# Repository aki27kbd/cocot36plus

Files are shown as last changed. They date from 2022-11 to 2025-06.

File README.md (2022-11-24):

# cocot36plus

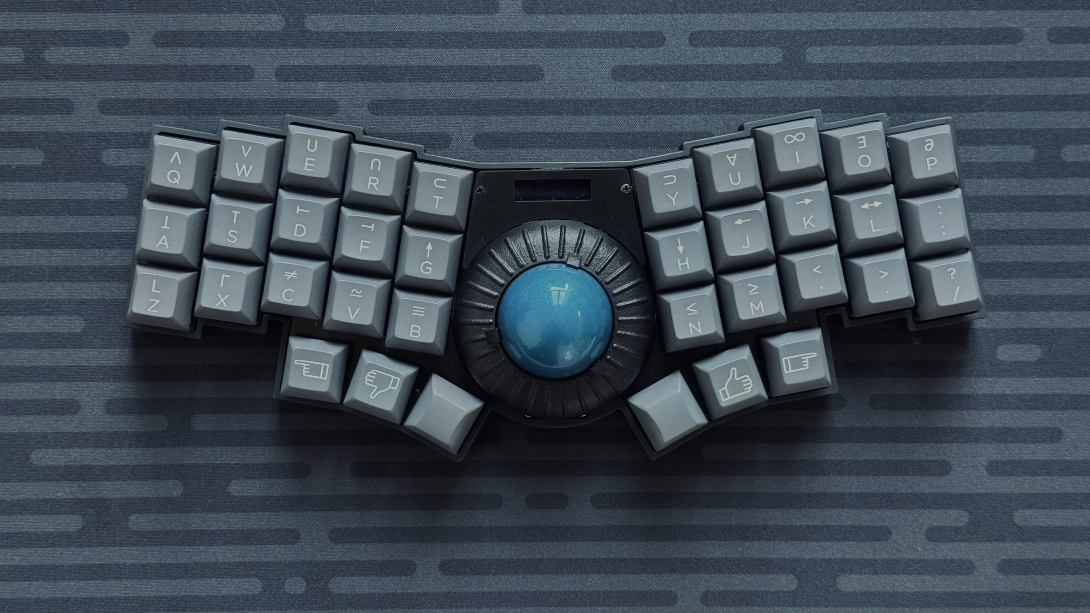
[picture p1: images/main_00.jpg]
cocot36plus_main00


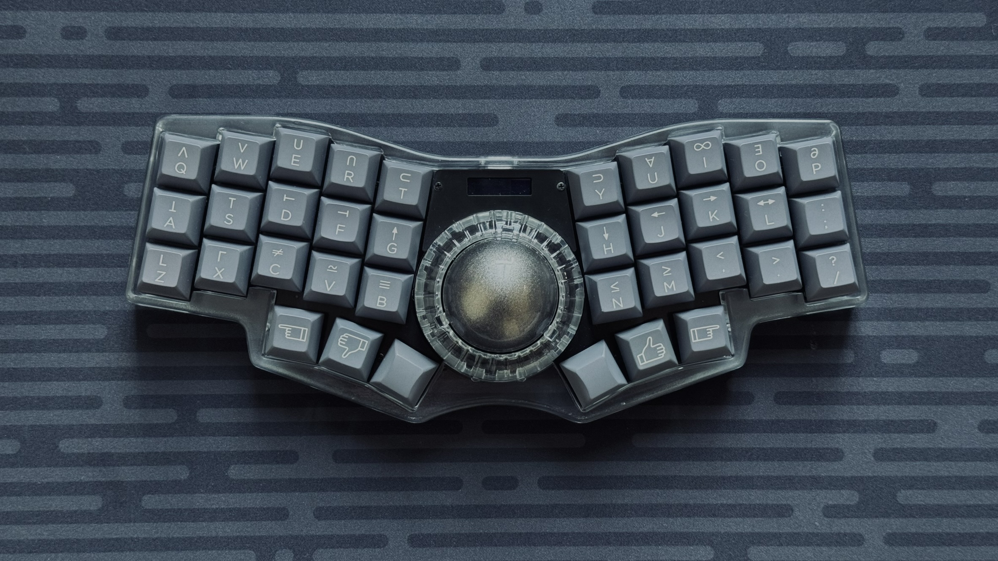
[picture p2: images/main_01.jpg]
cocot36plus_main01


cocot36plus is a column staggered keyboard with 36 keys, a 34mm-trackball and a scroll ring.

- Keyboard Maintainer: [aki27kbd](https://github.com/aki27kbd) [@aki27kbd](https://twitter.com/aki27kbd)
- Hardware Supported: cocot36plus PCB, RP2040 on board
- Hardware Availability: [BOOTH](https://aki27.booth.pm)

Build Guide [JP](doc/buildguide.md) / [EN](doc/buildguide_en.md)

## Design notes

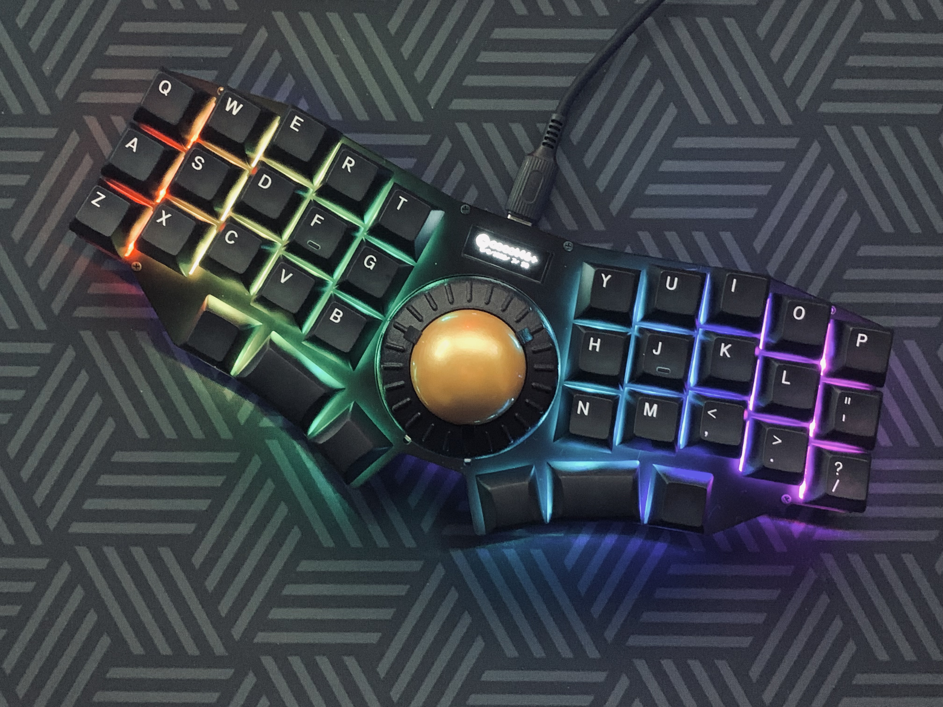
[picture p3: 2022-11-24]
v1/images/main_00.jpg

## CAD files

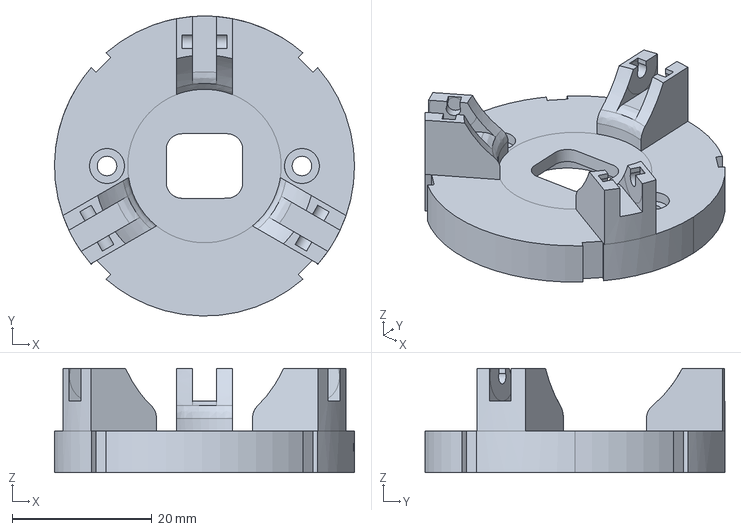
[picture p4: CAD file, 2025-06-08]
hardware/cocot36plus_v2_34mm_ballbase_rev.stp
43.0 x 43.0 x 15.0 mm

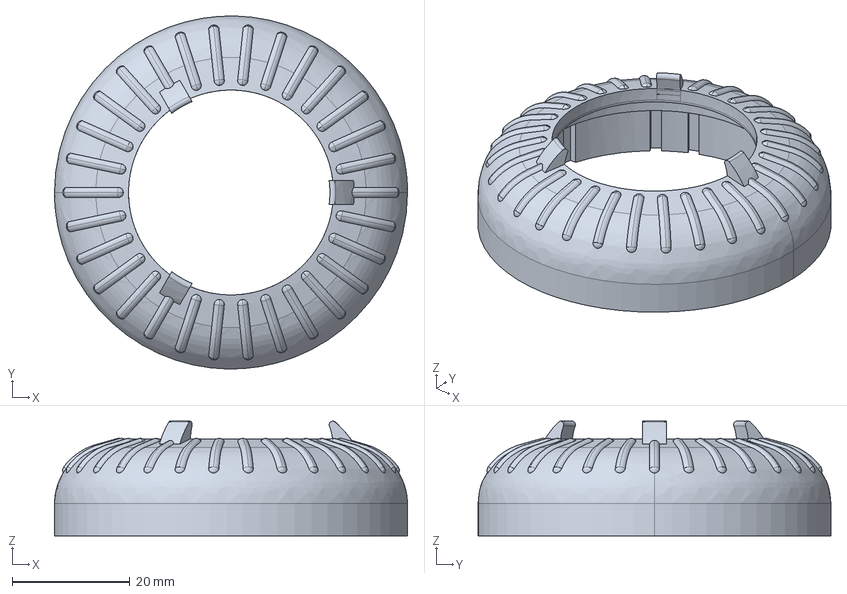
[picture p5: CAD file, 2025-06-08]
hardware/cocot36plus_v2_BallCover_34mm_MJF.stp
60.0 x 60.0 x 19.5 mm

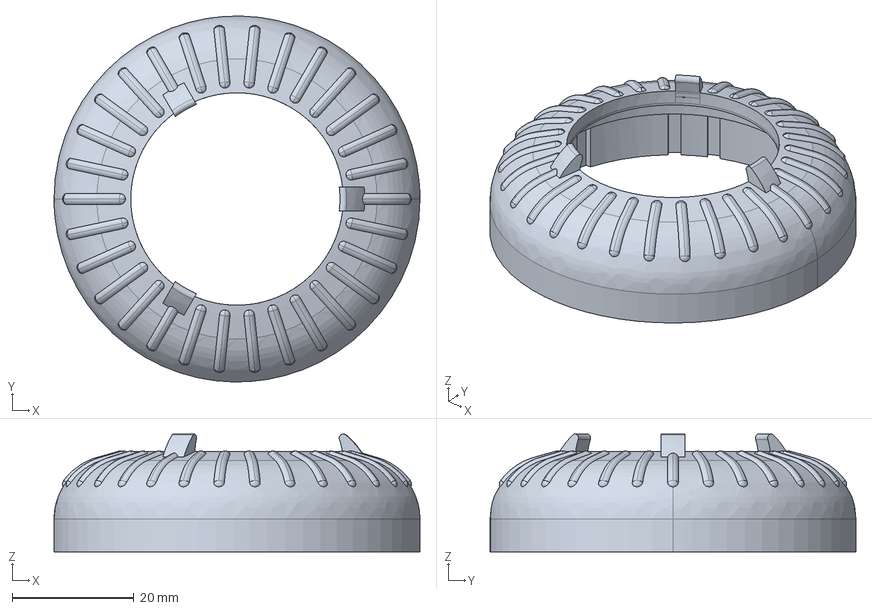
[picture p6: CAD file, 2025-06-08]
hardware/cocot36plus_v2_BallCover_34mm_ClearResin.stp
60.0 x 60.0 x 19.3 mm

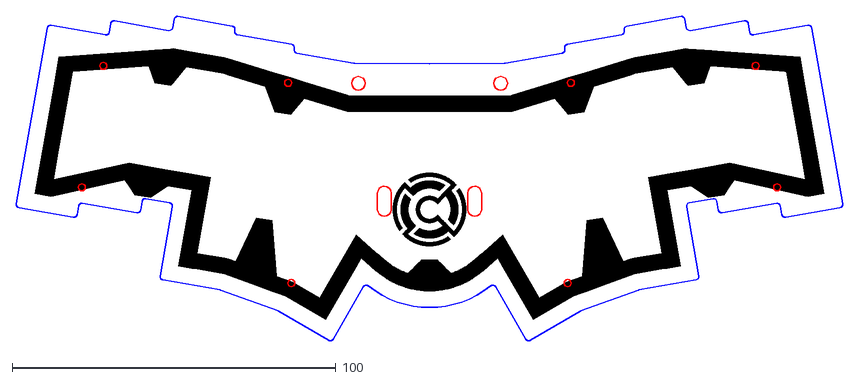
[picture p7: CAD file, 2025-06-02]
hardware/cocot36plus_v2_Acrylic_Bottom.dxf
255.4 x 100.3

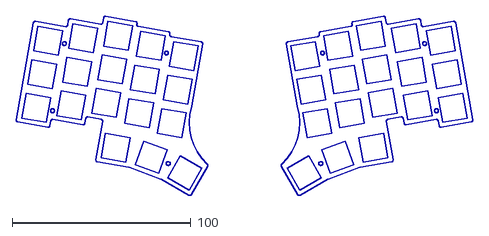
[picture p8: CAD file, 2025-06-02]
hardware/cocot36plus_v2_Switch_Plate.dxf
255.5 x 100.4

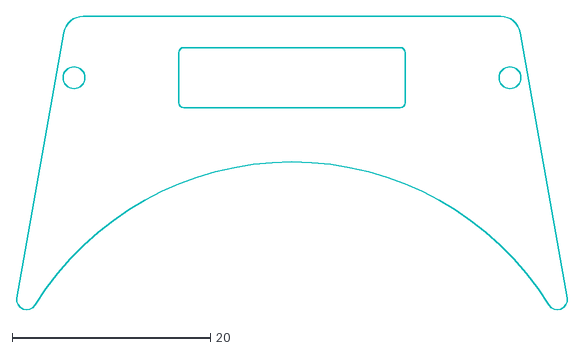
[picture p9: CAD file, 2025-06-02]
hardware/cocot36plus_v2_Cover_Plate.dxf
55.7 x 29.7

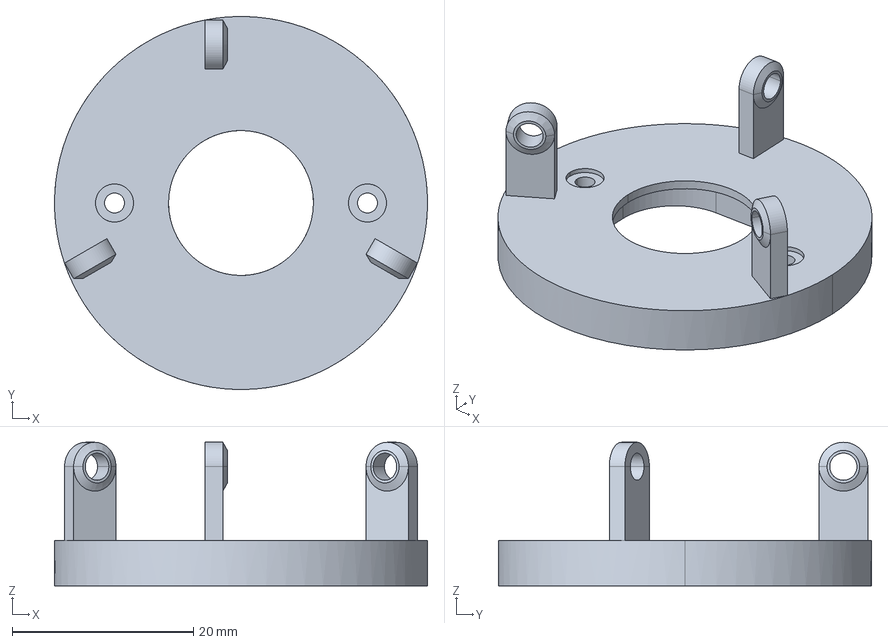
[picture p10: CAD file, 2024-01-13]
hardware/BallBase_34mm_Bearing.stp
41.2 x 41.2 x 15.9 mm

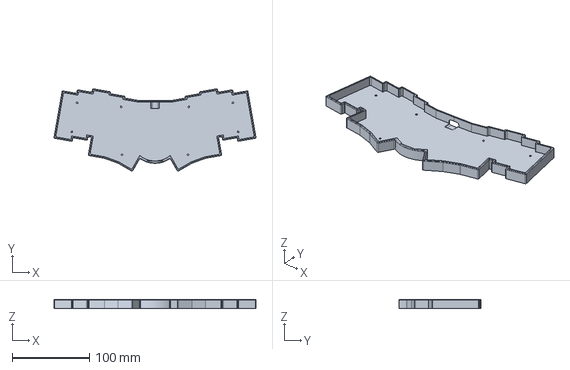
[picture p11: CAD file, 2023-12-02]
hardware/cocot36plus_v2_TrayMountCase_LowPro.stp
261.1 x 106.5 x 11.6 mm

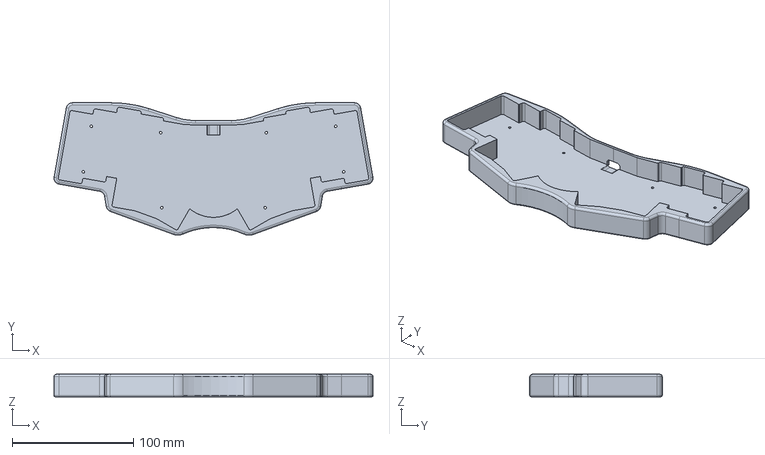
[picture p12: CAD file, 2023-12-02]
hardware/cocot36plus_v2_TrayMountCase.stp
263.3 x 109.4 x 18.6 mm

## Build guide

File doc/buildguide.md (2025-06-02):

# Build Guide

cocot36plus_main00

cocot36plus_main01

cocot36plus v2のビルドガイドになります。  
v1のビルドガイドは[こちら](https://github.com/aki27kbd/cocot36plus/blob/main/v1/doc/buildguide.md)を参照してください。

cocot36plusは中央に34mmトラックボールとスクロールリングを搭載したカラムスタッガード30%キーボードです。コンパクトながら豊富な機能を搭載しています。
- 中央にトラックボールとスクロールリングを配置
- フルキーバックライト & アンダーグロウLED & RGBマトリクス対応
- MCUはオンボードRP2040

また、ボールカバーを兼ねたスクロールリングは逆さにしてもボールが落ちず、かつ片手でボールの着脱が可能な設えとなっています。容易なボールのメンテナンスが可能となりました。

## 部品
### キット付属品

|名前|数|備考|
|---|---|---|
|PCB|1枚||
|スイッチプレート|2枚||
|アクリルボトムプレート|1枚||
|マウスセンサー（PMW3360）|1個||
|リングエンコーダ（PER601）|1個||
|OLED|1個||
|OLED用ピンヘッダ|1個||
|OLED用ピンソケット|1個||
|ベアリングローラー|3個||
|ステンレス棒×3|3本|
|シリコンチューブ|1本|
|M2ねじ 8mm|2本|
|M2ナット|2個|
|M2ねじ 4mm|20本|
|M2スペーサー 9mm|10本||
|ゴム脚|6個||
|3Dプリントボールベース|1個||
|3Dプリントボールカバー|1個||

### キット以外に必要なもの

|名前|数|備考|
|---|---|---|
|キースイッチ|36個|MX互換|
|キーキャップ|36個|MX互換|
|トラックボール（34mmボール）|1個||
|USB-TypeCケーブル|1本||

## 組み立て
### 部品確認

  まずはキット付属品に記載されたパーツが揃っているか確認ください。  
  その他上述の「キット以外に必要なもの」を揃えた上で組み立てに取り掛かってください。

  - タブ付きPCBの場合にはタブを割って切り離し、切断面を軽くヤスリがけしてください。
  - PCB、スイッチプレートの側面を油性マジックなどで黒く塗ると見栄えが良くなります。ぜひ試してみてください。

  上:未塗装 / 下:塗装済  
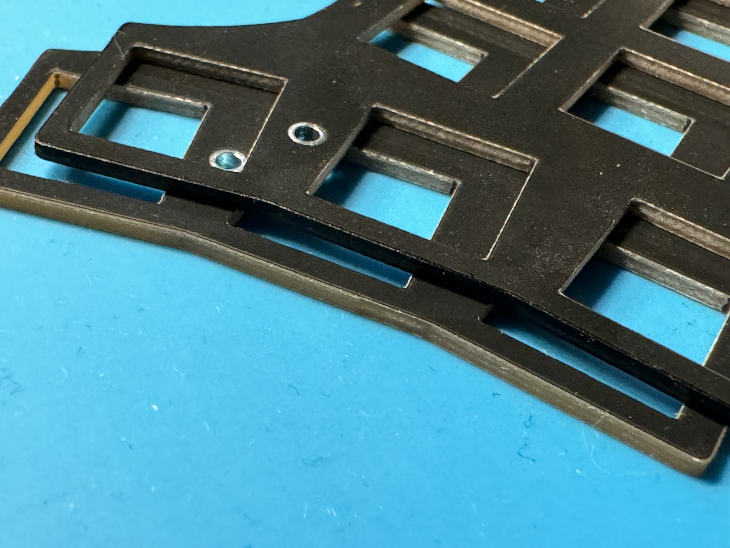
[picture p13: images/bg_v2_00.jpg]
cocot36plus_bg_00
  

### スイッチソケット

  スイッチソケットがはんだ付けされていない基板の場合、ソケットのはんだ付けを行ってください。  

### マウスセンサー

  マウスセンサー（PMW3360）を基板裏面から写真の向きに設置し、表面からはんだ付けを行います。シルクの●印と基板の●印の位置が合うように注意してください。  
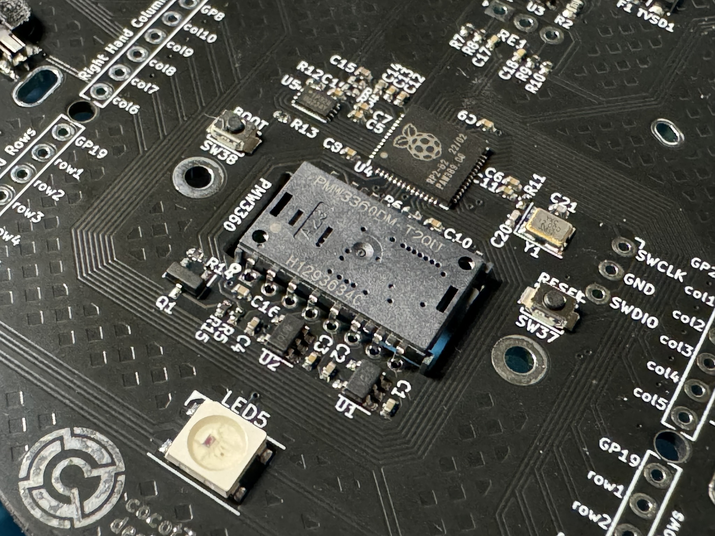
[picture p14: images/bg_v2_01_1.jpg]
cocot36plus_bg_01_1
  

  センサーの脚がしっかり奥まで入った状態で、浮かないようにマスキングテープなどで固定します。  
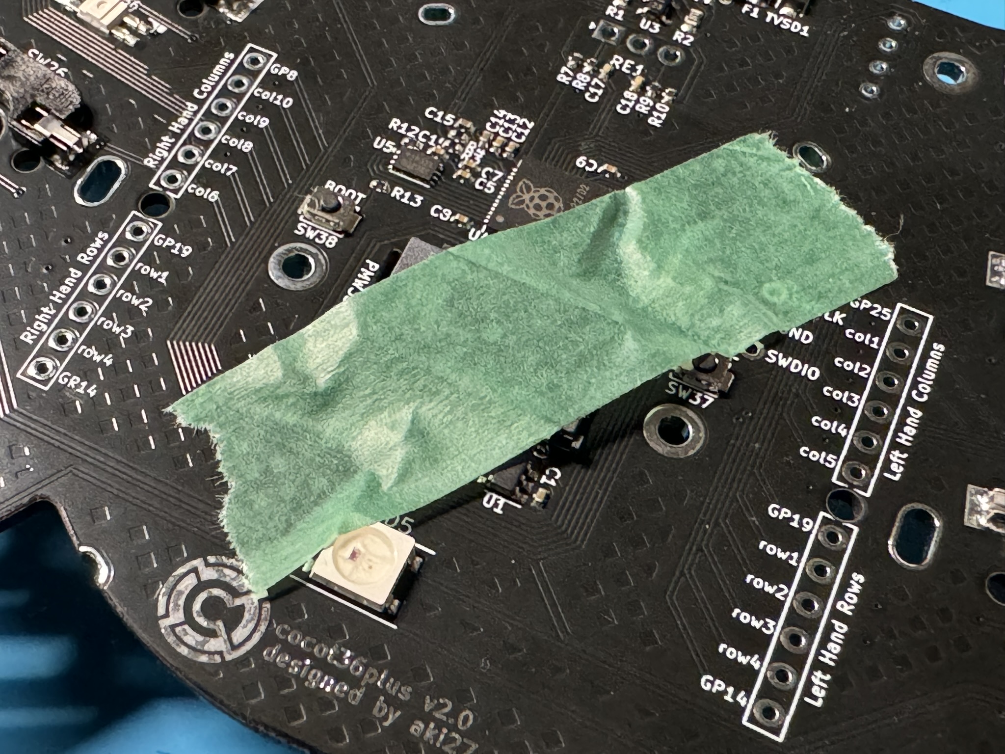
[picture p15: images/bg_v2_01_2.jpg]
cocot36plus_bg_01_2
  

  表面から16本の脚をはんだ付けします。センサーに貼られているテープを剥がし、表面からレンズを付けます。  
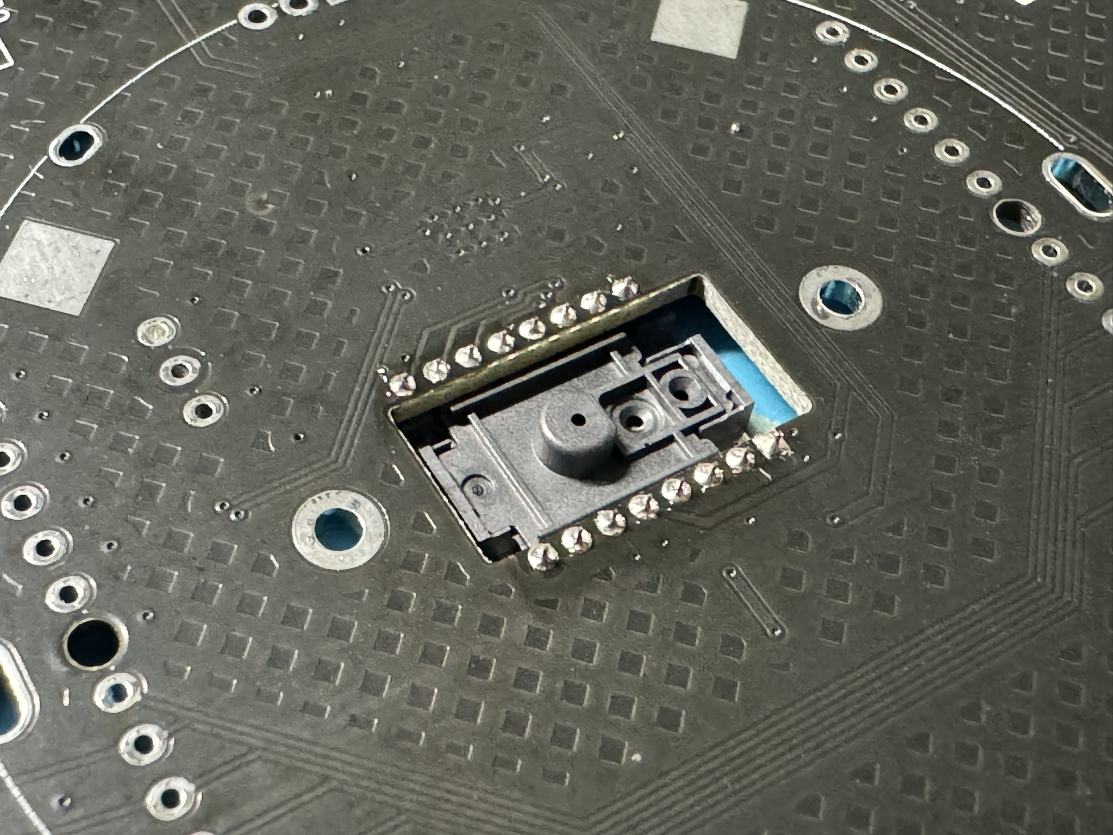
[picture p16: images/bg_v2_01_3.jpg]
cocot36plus_bg_01_3
  

### OLED

  OLED用ピンソケットをPCB表側から挿し、マスキングテープなどで固定します。
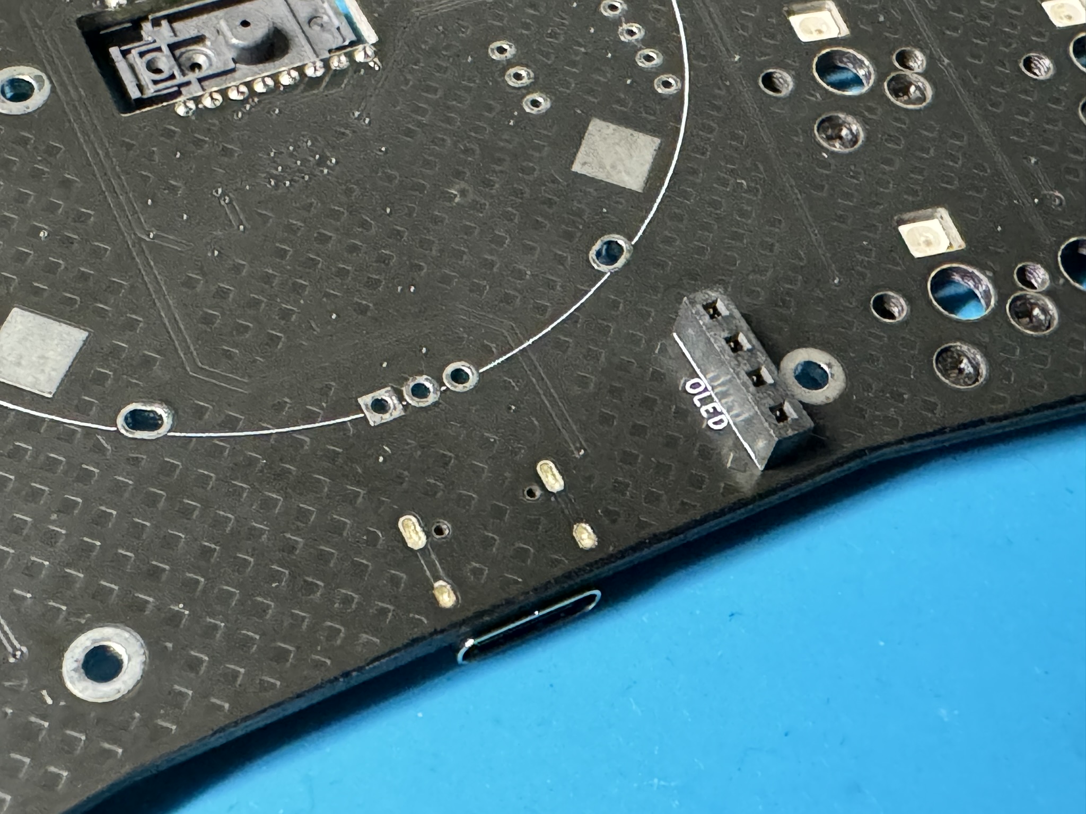
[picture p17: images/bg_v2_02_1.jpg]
cocot36plus_bg_02_1
  

  PCB裏面からピンソケットの脚4本をはんだ付けします。
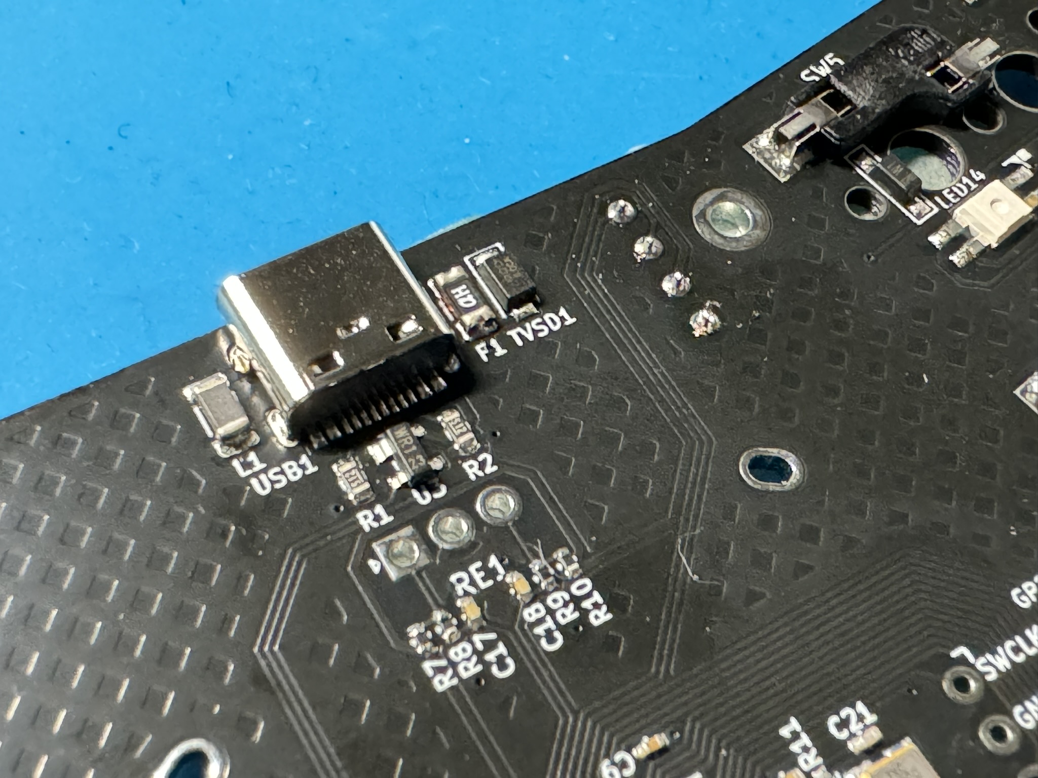
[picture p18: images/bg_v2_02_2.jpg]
cocot36plus_bg_02_2
  

  ピンヘッダを表側から挿し、その上からOLEDを挿します。OLEDの上面より飛び出しているピンヘッダをニッパーでカットし、はんだ付けします。OLEDモジュールが傾かないように固定した上ではんだ付けを行ってください。  
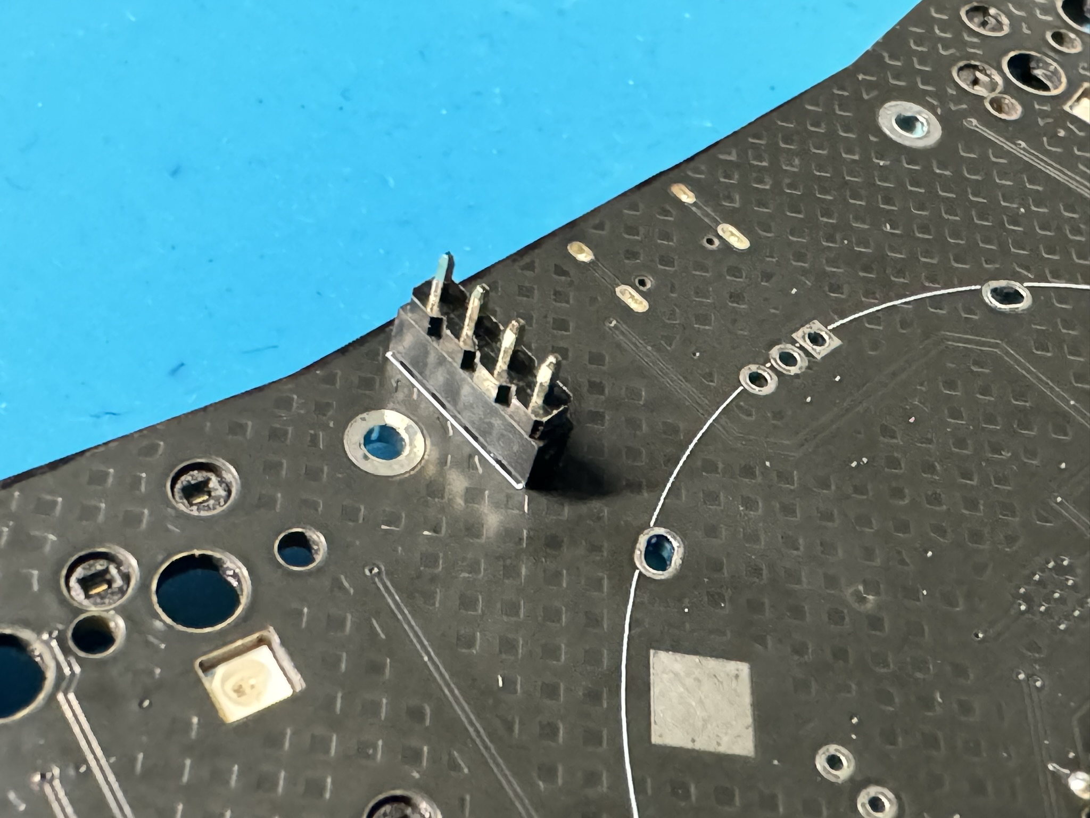
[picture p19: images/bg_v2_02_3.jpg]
cocot36plus_bg_02_3
  

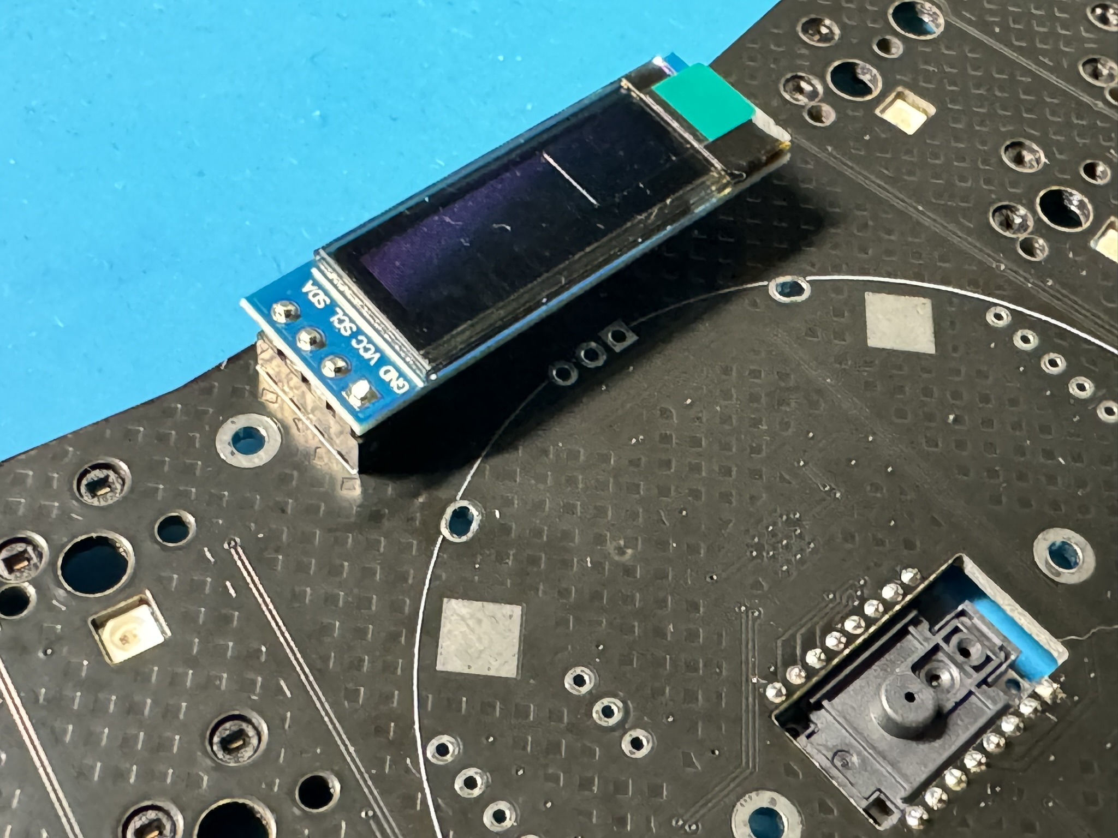
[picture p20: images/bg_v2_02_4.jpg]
cocot36plus_bg_02_4
  

### スクロールリング

  スクロールリングをPCB表面から差し込み、裏面の3か所はんだ付けを行います。  
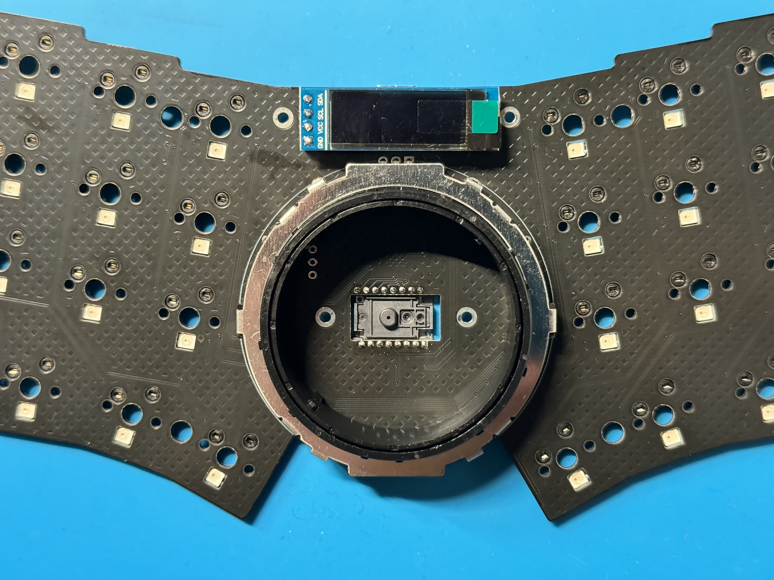
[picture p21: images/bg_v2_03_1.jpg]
cocot36plus_bg_03_1
  

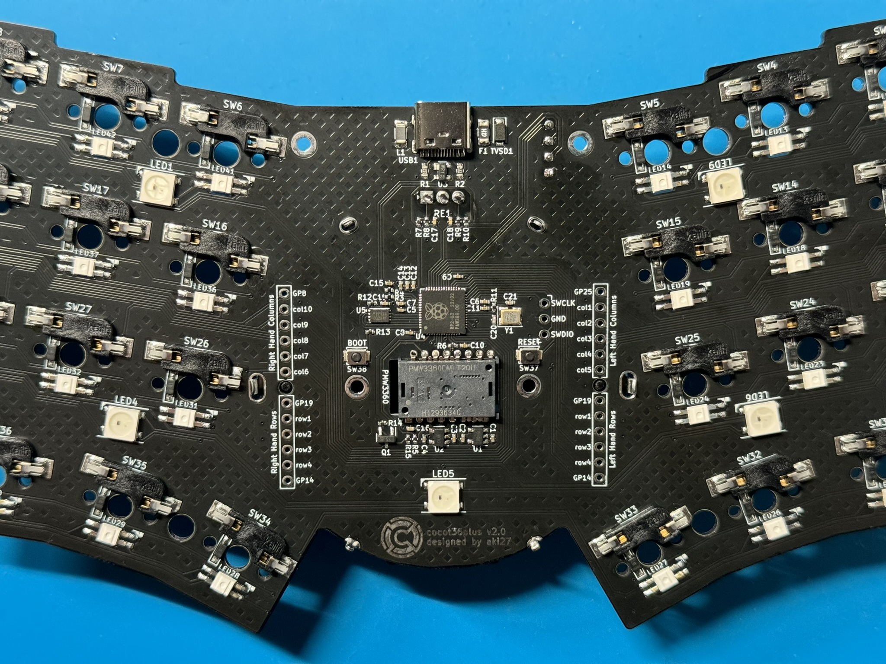
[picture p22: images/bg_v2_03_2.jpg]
cocot36plus_bg_03_2
  

### 組み立て

  ボールベースにベアリングローラーを固定します。写真の向きに合わせてベアリングローラー、M3ネジ、M3ナットで固定します。ベアリングを支持する3本の柱の両サイドのうち、ベアリングが固定されるのが突起のある面、ナットが触れるのが平坦な面になります。
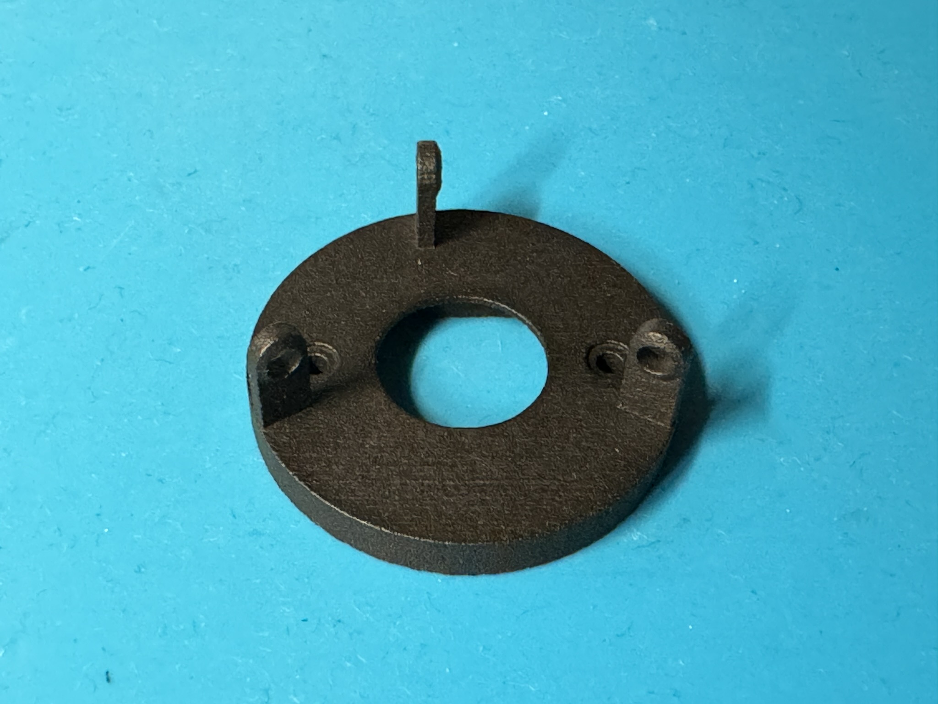
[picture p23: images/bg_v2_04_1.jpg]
cocot36plus_bg_04_1
  

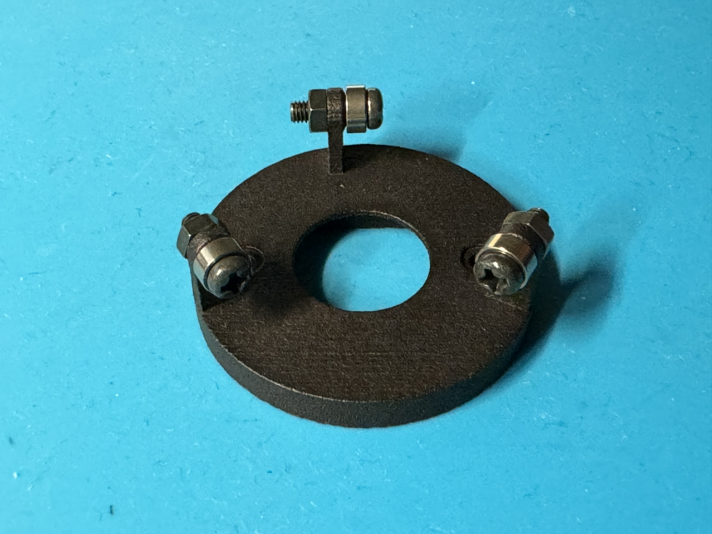
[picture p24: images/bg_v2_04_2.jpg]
cocot36plus_bg_04_2
  

  シリコンチューブが含まれているロットの場合、ボールケースの組み立ては[picot5400](https://github.com/aki27kbd/picot5400/blob/main/doc/buildguide.md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)を参照してください。

  マウスセンサーを固定しレンズを装着したPCBにボールベースを被せます。表面からM2 8mmネジ、裏面からナットで固定します。
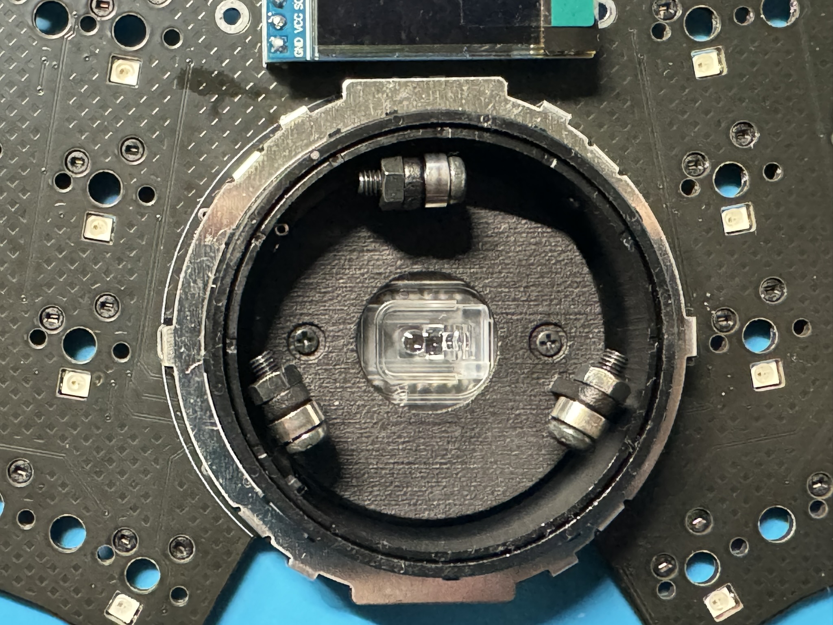
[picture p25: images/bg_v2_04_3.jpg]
cocot36plus_bg_04_3
  

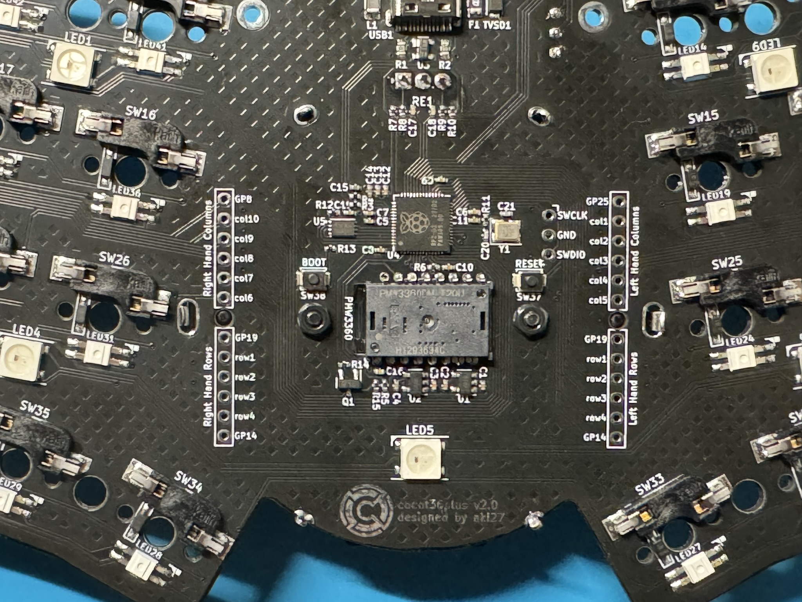
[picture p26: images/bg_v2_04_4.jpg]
cocot36plus_bg_04_4
  

  ボトムプレートに4mmネジで9mmスペーサーを固定します。  
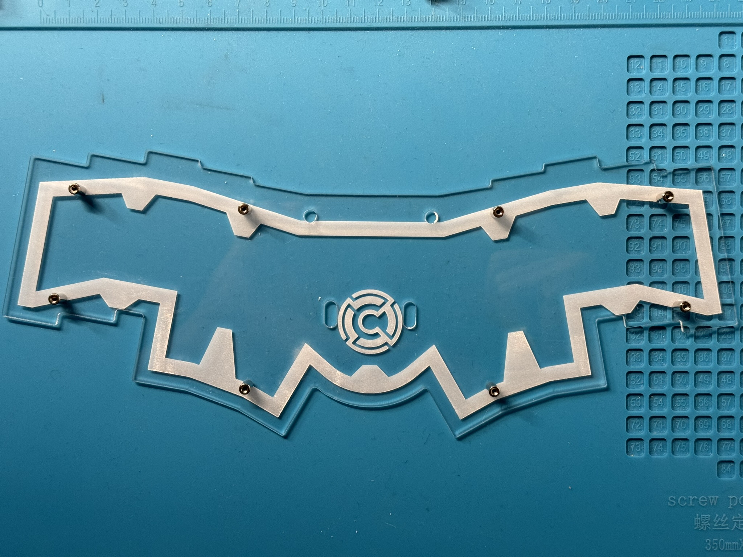
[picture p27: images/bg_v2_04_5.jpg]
cocot36plus_bg_04_5
  

  OLED横の穴に4mmネジで9mmスペーサーを固定します。  
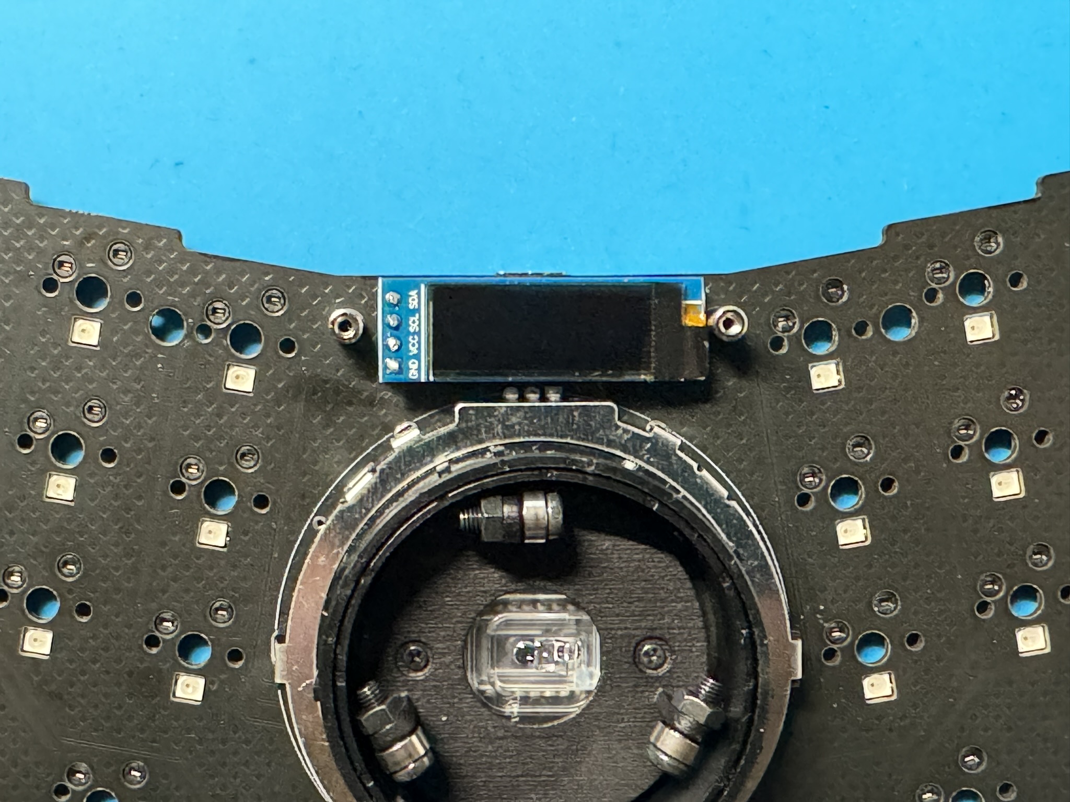
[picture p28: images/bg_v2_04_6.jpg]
cocot36plus_bg_04_6
  

  OLEDカバープレートをその上から被せ、M2ネジで固定します。このタイミングでボールカバーもリングエンコーダ―に取り付けます。緩い場合は内側にテープなどを貼り固定します。　　
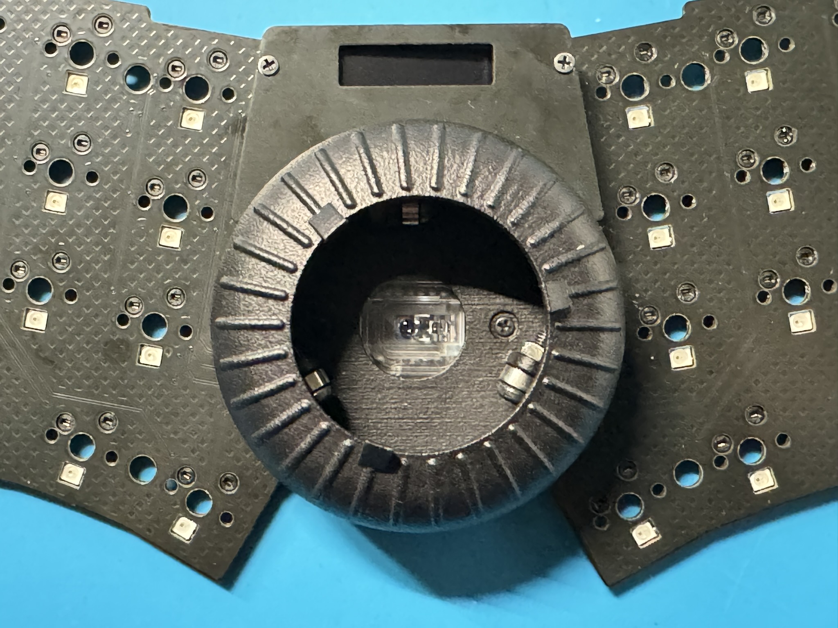
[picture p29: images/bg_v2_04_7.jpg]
cocot36plus_bg_04_7
  

  スイッチプレートと基板を重ね、隅から順番にキースイッチをはめていきます。スイッチの向きに気を付けて、またスイッチの脚が曲がらないように真っすぐに差し込むようにしてください。  
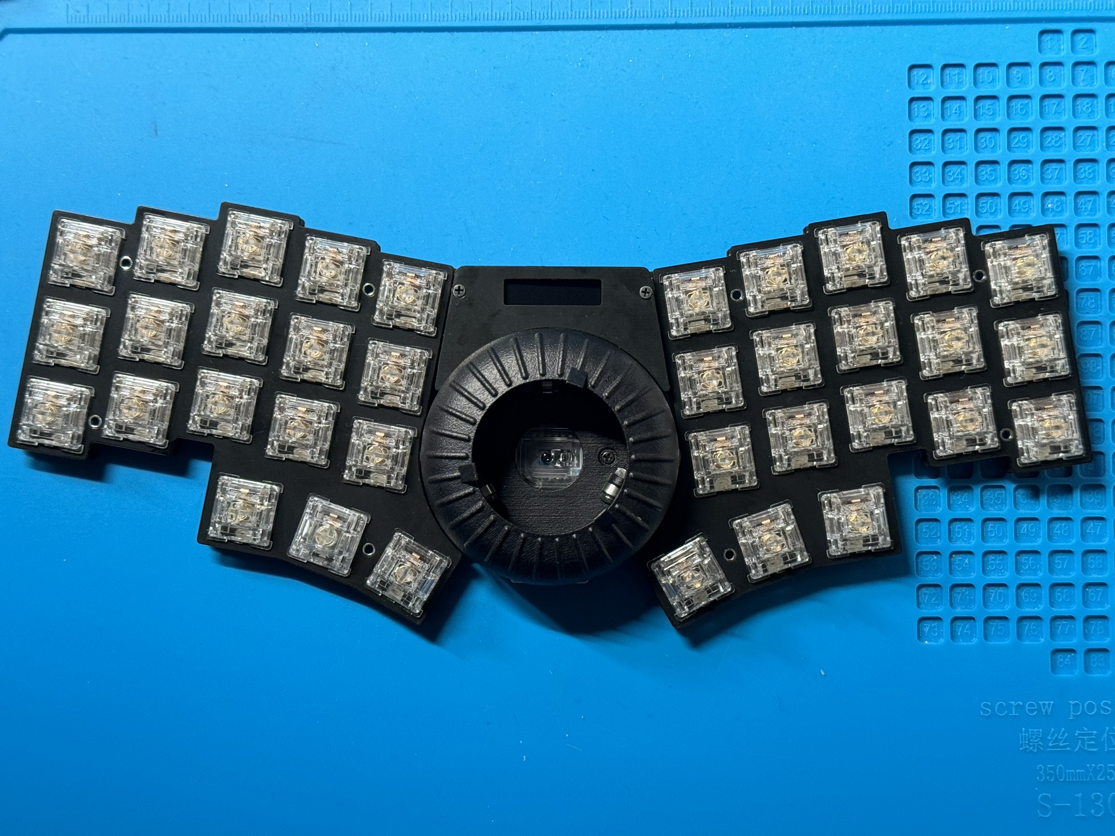
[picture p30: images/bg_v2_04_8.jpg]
cocot36plus_bg_04_8
  

  スイッチを差し込んだスイッチプレート&基板を、ボトムプレートの上に重ねます。スイッチプレート表面から4mmネジで8か所固定します。  
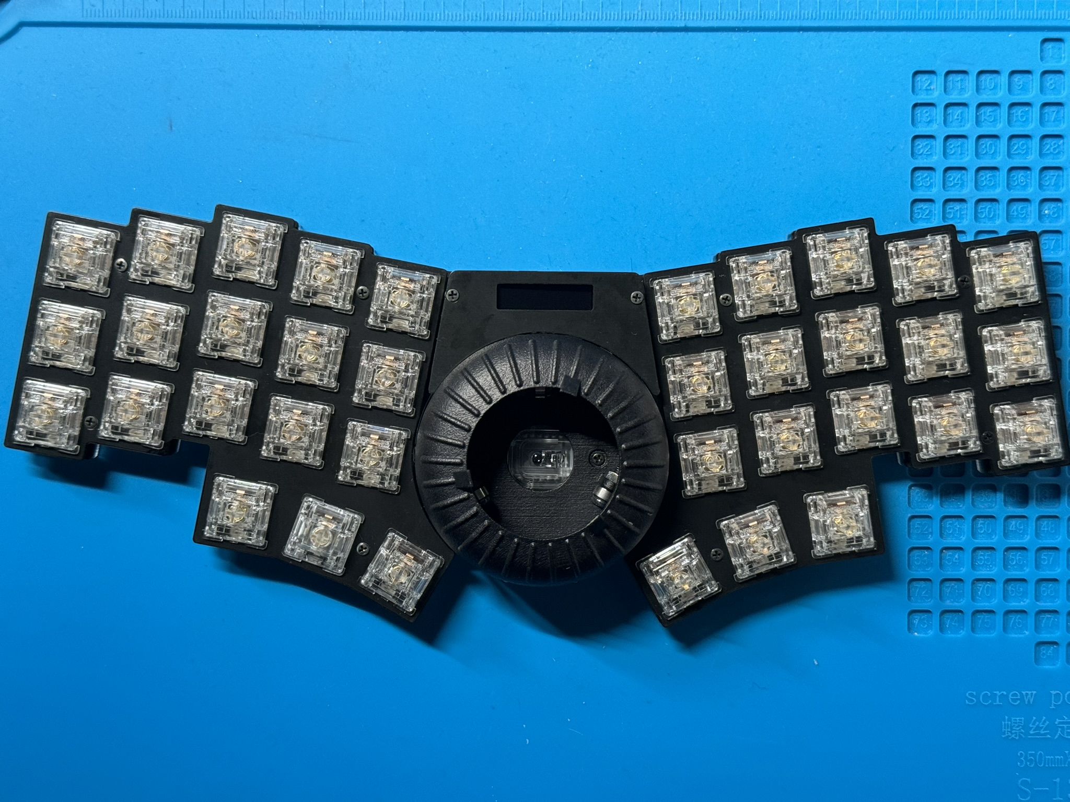
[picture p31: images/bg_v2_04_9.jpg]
cocot36plus_bg_04_9
  

  裏面にゴム脚を貼り付けます。  
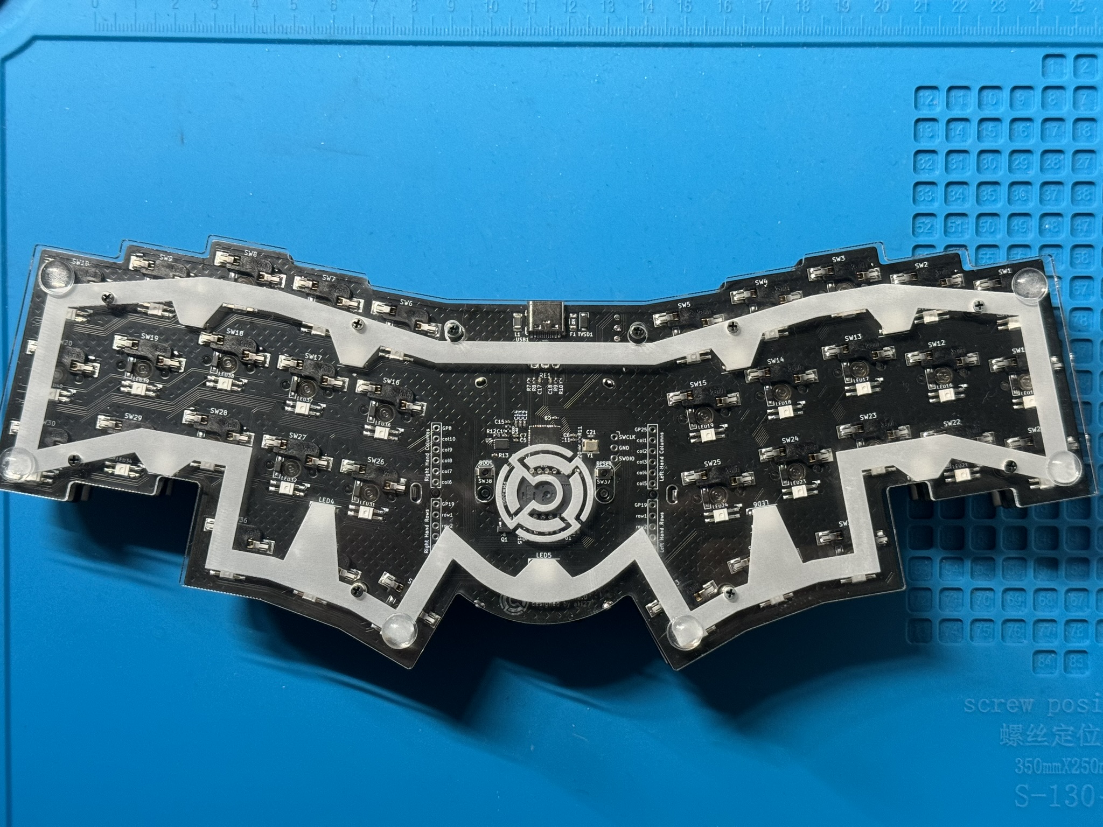
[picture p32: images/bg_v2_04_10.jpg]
cocot36plus_bg_04_10
  

  ボール、キーキャップをはめて完成です。
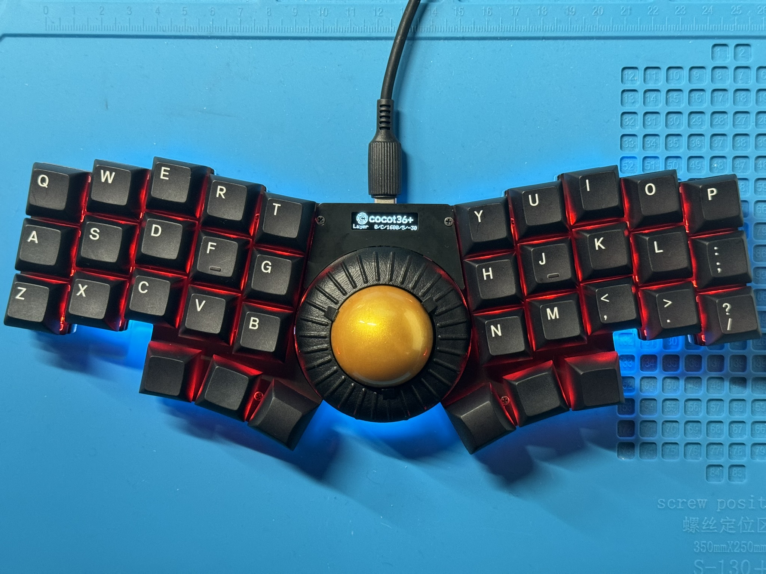
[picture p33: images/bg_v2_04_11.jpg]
cocot36plus_bg_04_11
  

## ファームウェア

デフォルトのファームが書き込まれた状態でお届けしています。ご自分でファームを書き込む場合、下記手順の通り実行してください。

  - 裏面のBOOTボタンを押しながらRESETボタンを押し、ブートローダーモードに入ります。
  - その状態でRPI-RP2というドライブに[.uf2](https://github.com/aki27kbd/cocot36plus/blob/main/firmware/aki27_cocot36plus_auto_mouse.uf2)ファイルをドラッグ&ドロップすることでファームが書き込まれます。

2024年1月以降出荷のデフォルトのファームウェアでは、トラックボールを動かした際に自動でマウス専用レイヤー（レイヤー4）に移動するように設定されています。それ以前の購入された方は[こちら](https://github.com/aki27kbd/cocot36plus/blob/main/firmware/aki27_cocot36plus_v2_vial.uf2)を書き込んでご利用ください。

キーマップは[vial](https://vial.rocks/)から更新可能です。  
トラックボール、LED含めて上記.uf2ファイルで確認いただけます。

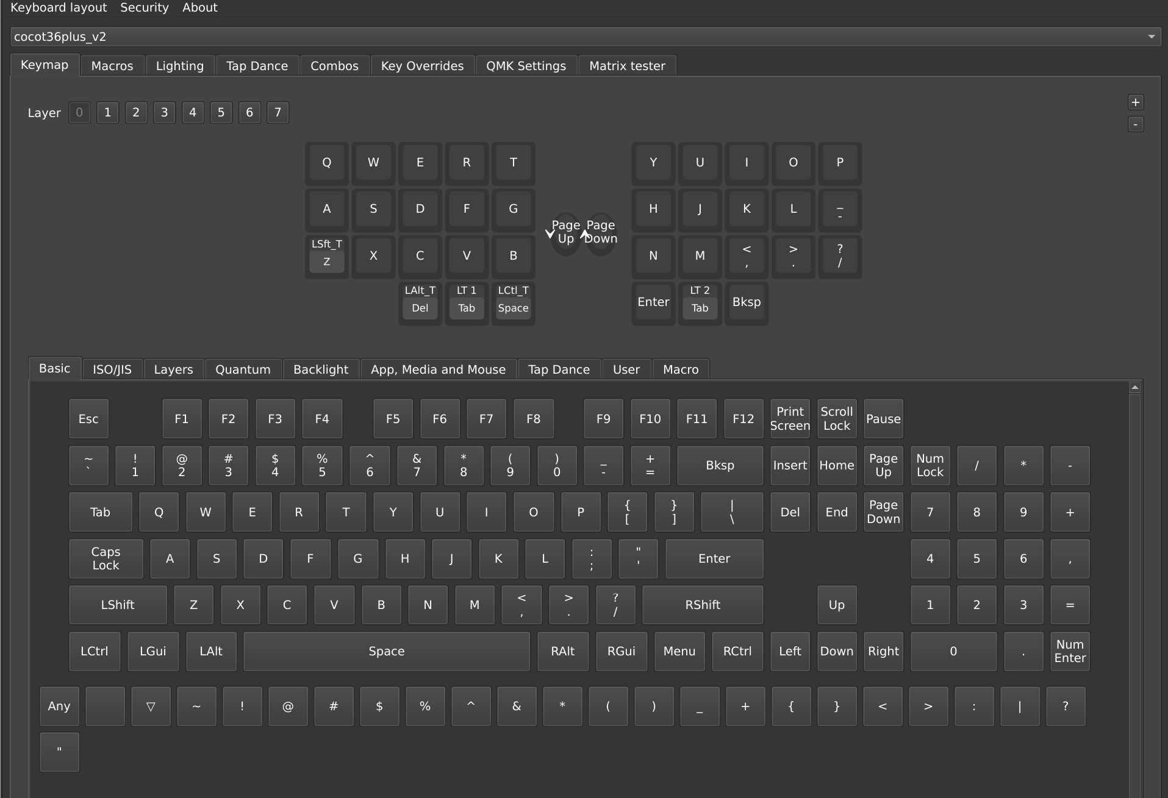
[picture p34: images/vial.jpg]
vial


ソースコードは[こちら](https://github.com/aki27kbd/vial-qmk/tree/vial/keyboards/aki27/cocot36plus)を参照ください。    

## カスタムキーコード

  トラックボールの操作に関していくつかカスタムキーコードを設定することが可能です。（SCRL_MOはレイヤー4でのみ有効）

  Keycode   |Description
  ---------|-----------
  `CPI_SW`  |トラックボールのCPIを変更します。デフォルトのファームウェアでは、押すたびに200→400→800→1600→3200→200…という順番でCPIが変わります。
  `SCRL_SW` |スクロールモードにおけるセンサーの感度を変更します。数値が大きいほどスクロール量が小さくなります。
  `ROT_R15` |マウスセンサーのＹ軸を時計回りに15度回転させます。
  `ROT_L15` |マウスセンサーのＹ軸を反時計回りに15度回転させます。
  `SCRL_MO` |押されている間スクロールモードになります。（デフォルトファームではレイヤー4でのみ有効）
  `SCRL_TO` |押すたびにスクロールモードとマウスモードを切り替えます。（デフォルトファームでは無効）
  `SCRL_IN` |スクロール方向を反転させます。
  `AM_TOG` |自動マウスレイヤー切り替えのオンオフを切り替えます。

  vialでカスタムキーコードを設定する場合はUserタブ下のカスタムキーコードを用いて設定することが可能です。  
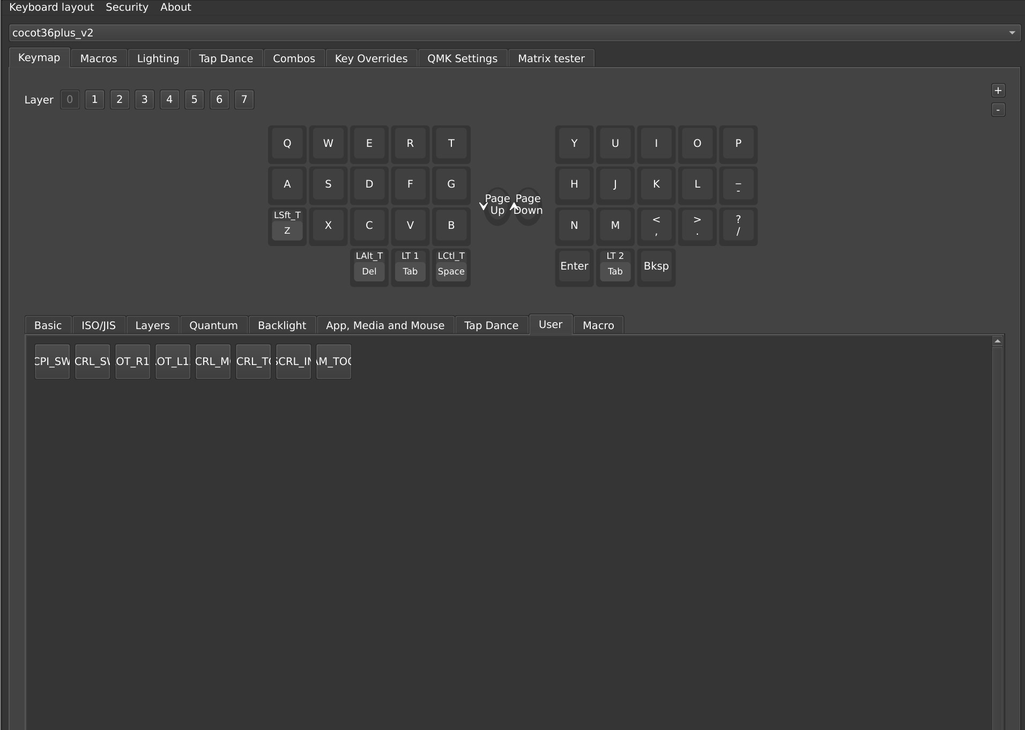
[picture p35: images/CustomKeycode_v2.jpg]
CustomKeycode_rev
  

## OLED

  OLEDにはトラックボールの情報を表示することが可能です。（画像はcocot46plusのものになります。）  
  cocot46plus_bg_oled_1

  OLED|Description
  ---------|-----------
  Current Layer|現在のレイヤーを示します。
  Scroll Status|C:カーソル/S:スクロールモードを示します。
  Auto Mouse Status|Y:自動マウスレイヤーオン/N:自動マウスレイヤーオフを示します。
  CPI|カーソルモードのCPIを示します。
  Scroll Divider|スクロールモードにおけるセンサーの感度を示します。数値が大きいほどスクロール量が小さくなります。
  Rotation Angle|マウスセンサーのY軸の回転角を示します。

  手の大きさやトラックボールへの手の置き方によって、操作しやすいY軸の回転角が異なります。`ROT_R15`、`ROT_L15`キーで調整しながら自分に合った設定を探してみてください。  
  cocot46plus_bg_oled_2_2

  cocot46plus_bg_oled_3_4_5

## 終わりに
何かトラブルがあれば[Twitterアカウント](https://twitter.com/aki27kbd)までご連絡ください。

また、完成写真をSNSにアップいただけるととても励みになります。（アップするのがはばかられる方はDMで直接送りつけていただいても構いません。）

ハッシュタグは #cocot36plus です。

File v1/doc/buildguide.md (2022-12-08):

# Build Guide

cocot36plus_main00

cocot36plusのビルドガイドになります。

cocot36plusは中央に34mmトラックボールとスクロールリングを搭載したカラムスタッガード30%キーボードです。コンパクトながら豊富な機能を搭載しています。
- 中央にトラックボールとスクロールリングを配置
- フルキーバックライト & アンダーグロウLED & RGBマトリクス対応
- MCUはオンボードRP2040

また、ボールカバーを兼ねたスクロールリングは逆さにしてもボールが落ちず、かつ片手でボールの着脱が可能な設えとなっています。容易なボールのメンテナンスが可能となりました。

## 部品
### キット付属品

|名前|数|備考|
|---|---|---|
|実装済基板|1枚||
|スイッチプレート|1枚||
|ボトムプレート|1枚||
|マウスセンサー（PMW3360）|1個||
|センサーレンズ|1個||
|リングエンコーダ|1個||
|OLEDモジュール+付属ピンヘッダ|1個||
|M2ねじ 4mm|16本|
|M2ねじ 8mm|2本|
|M2ナット|2個||
|M2スペーサー 9mm|8本||
|ゴム脚|6個||
|ボールホルダー|1個||
|ボールカバー|1個||

### キット以外に必要なもの

下記パーツは[遊舎工房](https://shop.yushakobo.jp/)、[TALP KEYBOARD](https://talpkeyboard.net/)、[Daily Craft Keyboard](https://shop.dailycraft.jp/)などで揃えることが可能です。

|名前|数|備考|
|---|---|---|
|USB-TypeCケーブル|1本||
|キースイッチ|36個|MX互換|
|キーキャップ|36個|MX互換|
|34mmボール|1個||

各ショップの在庫状況に応じて検討ください。

## 組み立て
### 0. 部品確認

  まずはキット付属品に記載されたパーツが揃っているか確認ください。  
  その他上述の「キット以外に必要なもの」および「オプション部品」を揃えた上で組み立てに取り掛かってください。

  - タブ付きPCBの場合にはタブを割って切り離し、切断面を軽くヤスリがけしてください。
  - PCB、スイッチプレートの側面を油性マジックなどで黒く塗ると見栄えが良くなります。ぜひ試してみてください。

  上:未塗装 / 下:塗装済  
  cocot36plus_bg_00

### 1. マウスセンサー

  マウスセンサー（PMW3360）を基板裏面から写真の向きに設置し、表面からはんだ付けを行います。シルクの●印と基板の●　印の位置が合うように注意してください。  
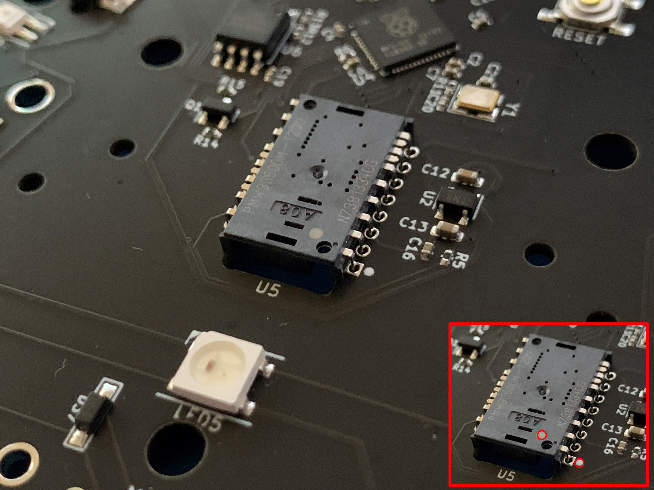
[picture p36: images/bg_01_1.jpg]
cocot36plus_bg_01_1
  

  センサーの脚がしっかり奥まで入った状態で、浮かないようにマスキングテープなどで固定します。  
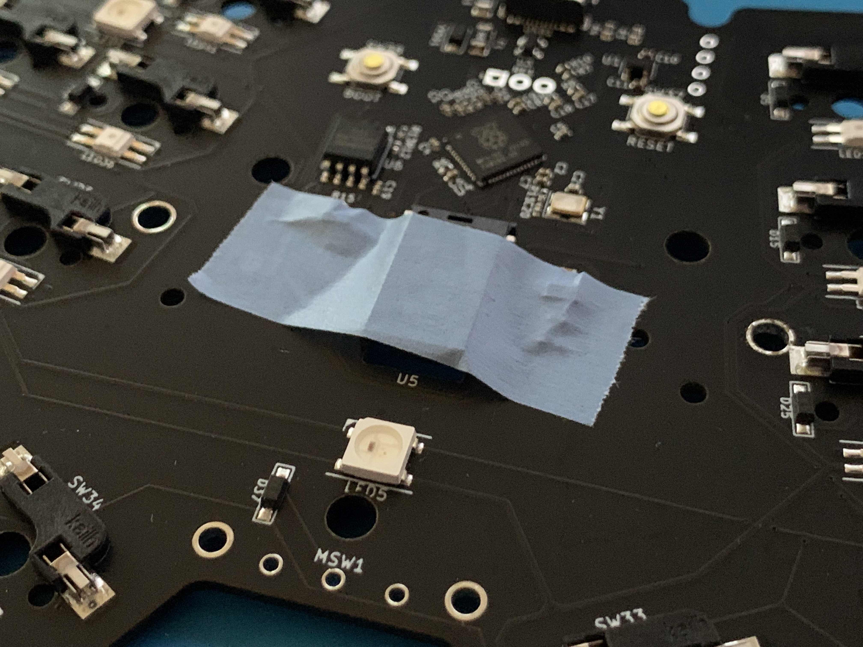
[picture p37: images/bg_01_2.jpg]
cocot36plus_bg_01_2
  

  表面から16本の脚をはんだ付けします。  
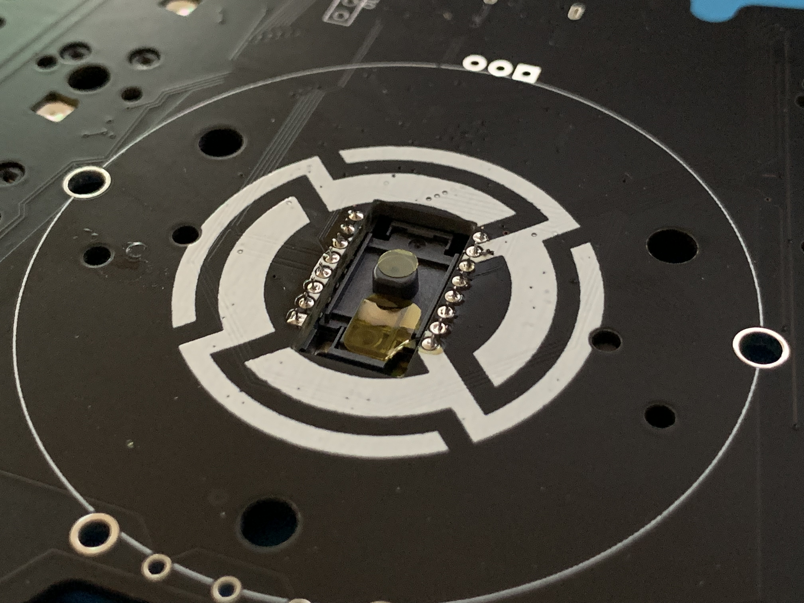
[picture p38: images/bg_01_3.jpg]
cocot36plus_bg_01_3
  

  センサーに貼られているテープを剥がし、表面からレンズを付けます。
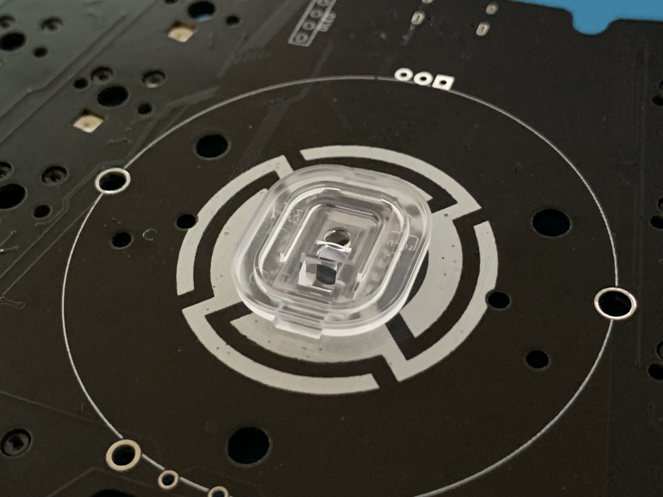
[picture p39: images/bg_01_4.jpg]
cocot36plus_bg_01_4
  

### 2. OLED

  OLEDピンヘッダを表側から挿し、マスキングテープなどで固定します。  
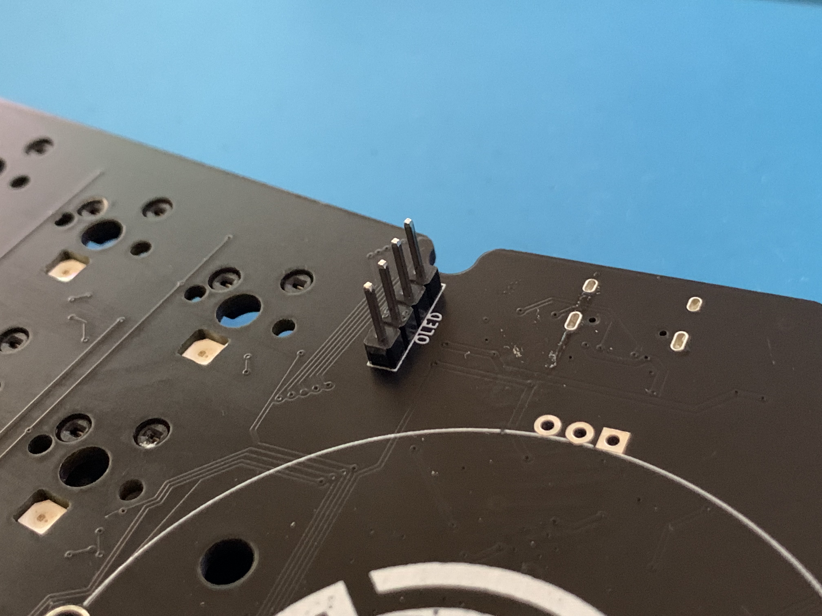
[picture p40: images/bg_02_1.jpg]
cocot36plus_bg_02_1
  

  基板裏側からピンヘッダの脚4本のはんだ付けを行ってください。  
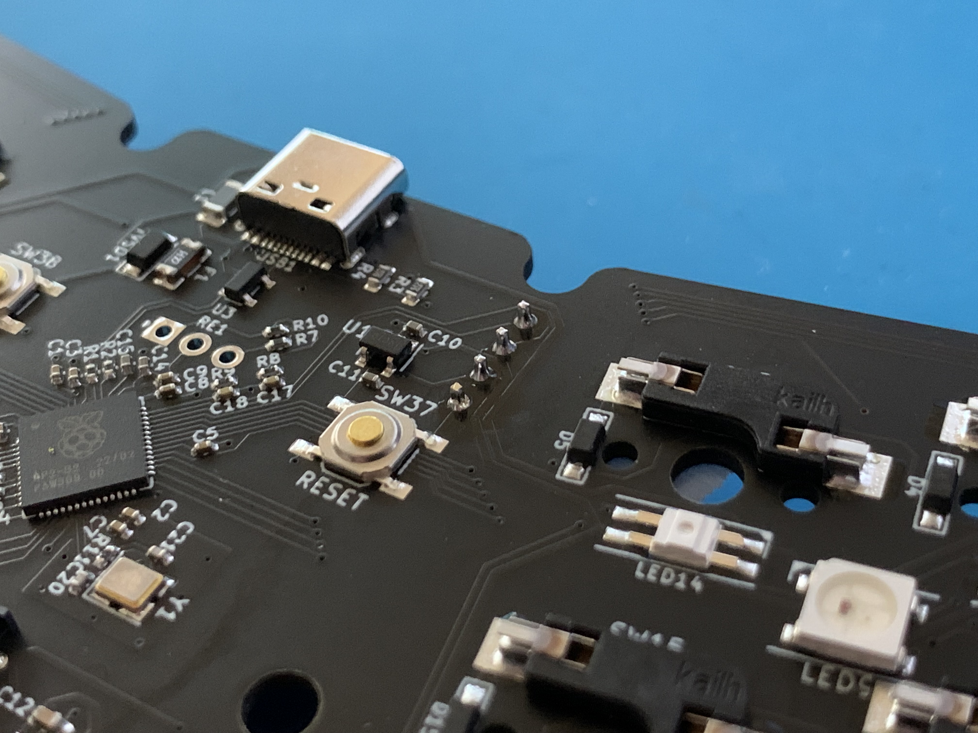
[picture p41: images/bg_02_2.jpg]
cocot36plus_bg_02_2
  

  ペンチなどでピンヘッダのプラスチック部分を取り外します。ゆっくり真っすぐ上に少しずつずらしていくイメージです。  
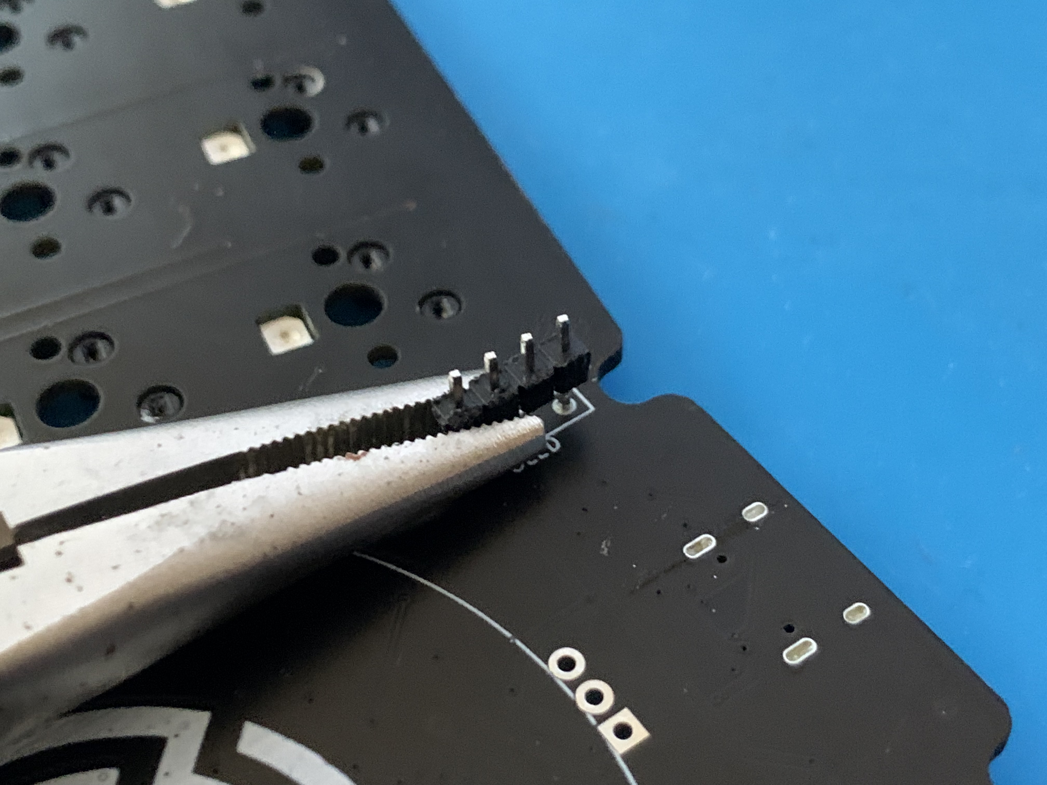
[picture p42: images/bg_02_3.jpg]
cocot36plus_bg_02_3
  

  OLEDモジュールの裏側にマスキングテープやカプトンテープを貼り絶縁します。  
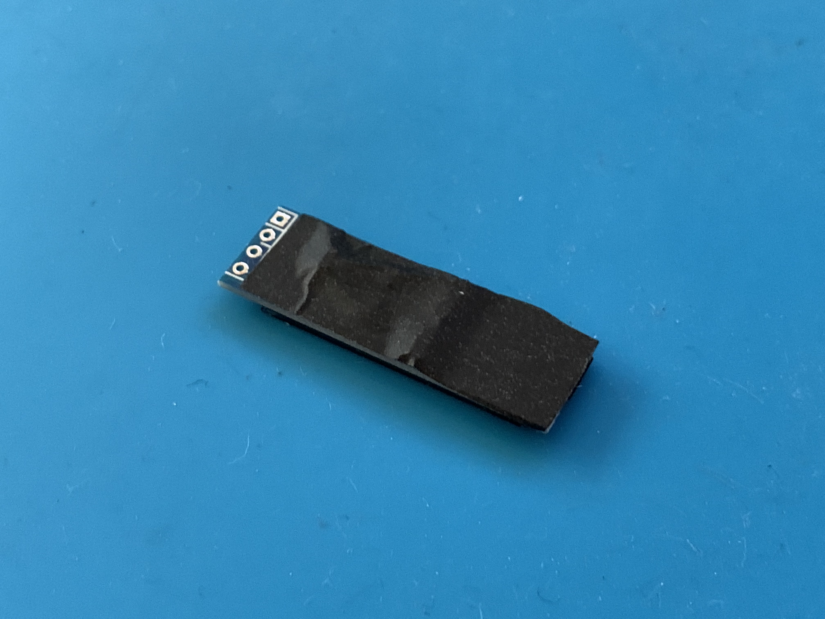
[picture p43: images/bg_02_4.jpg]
cocot36plus_bg_02_4
  

  OLEDモジュールをピンヘッダに通し、はんだ付けを行った後飛び出しているピンをカットします。OLEDモジュールが浮いていると後工程でスイッチプレートが浮いてしまうので、できるだけOLEDはPCBに近い位置で固定されるようにはんだ付けを行ってください。  
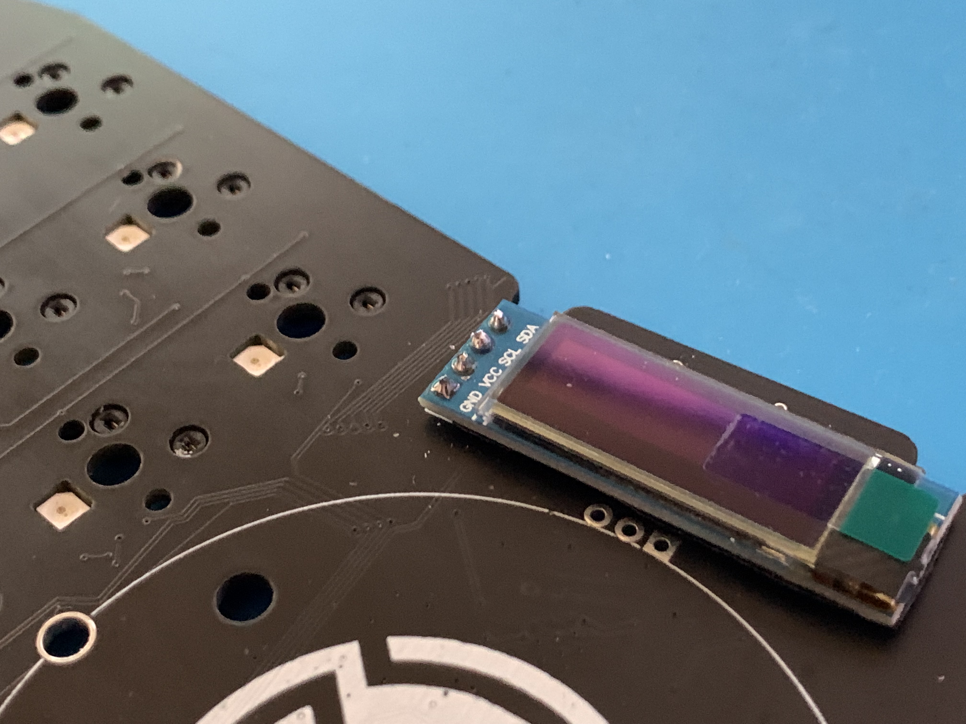
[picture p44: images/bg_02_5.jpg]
cocot36plus_bg_02_5
  

### 3. スクロールリング

  スクロールリングをPCB表面から差し込み、裏面の3か所はんだ付けを行います。  
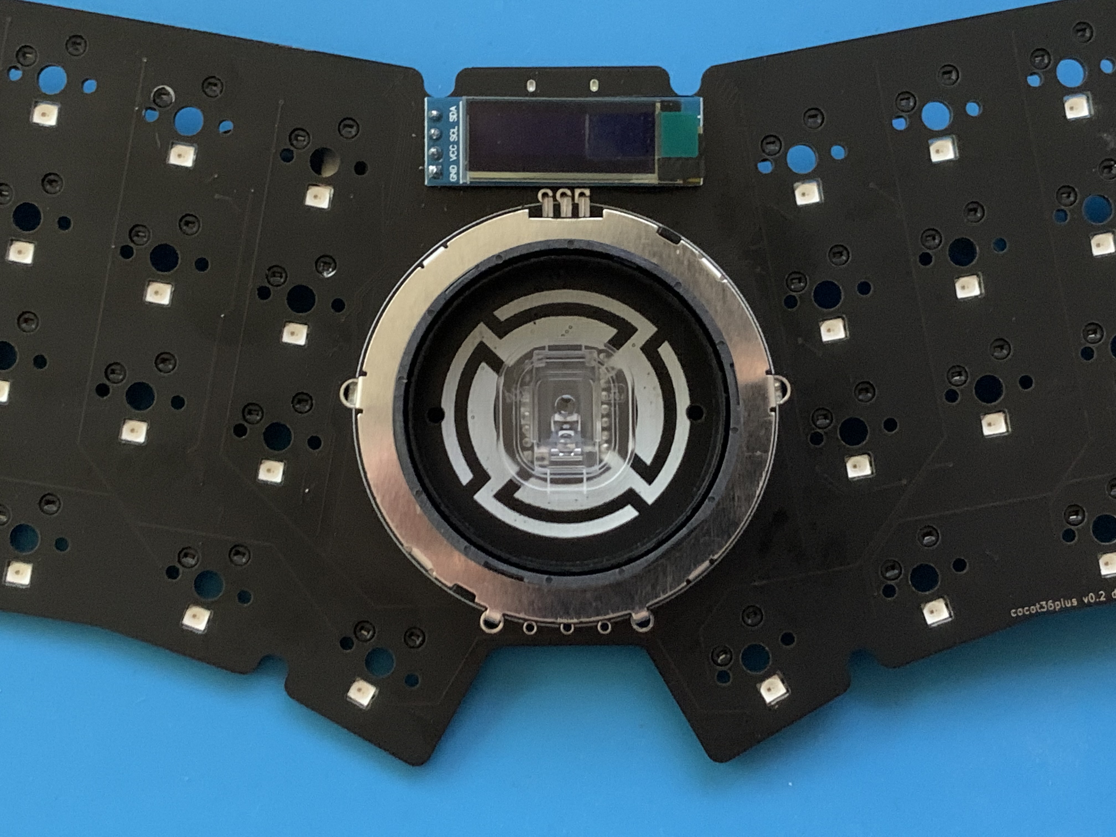
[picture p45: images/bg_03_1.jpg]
cocot36plus_bg_03_1
  

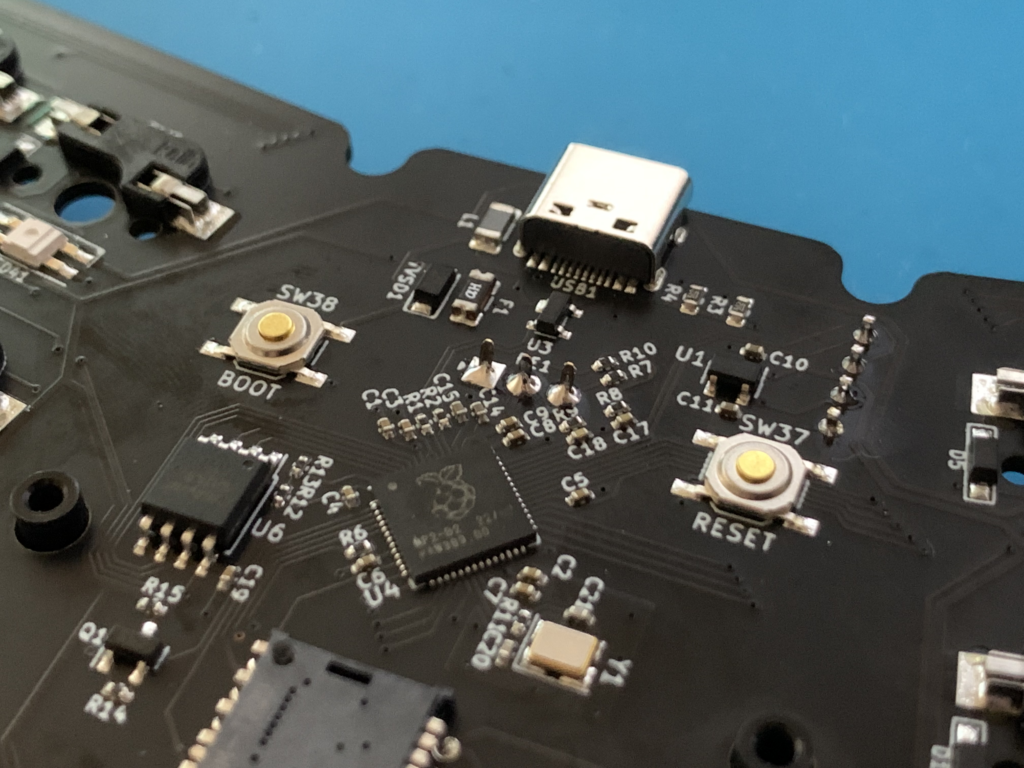
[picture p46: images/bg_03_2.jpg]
cocot36plus_bg_03_2
  

### 4. 組み立て

  ボトムプレートに4mmネジで9mmスペーサーを固定します。  
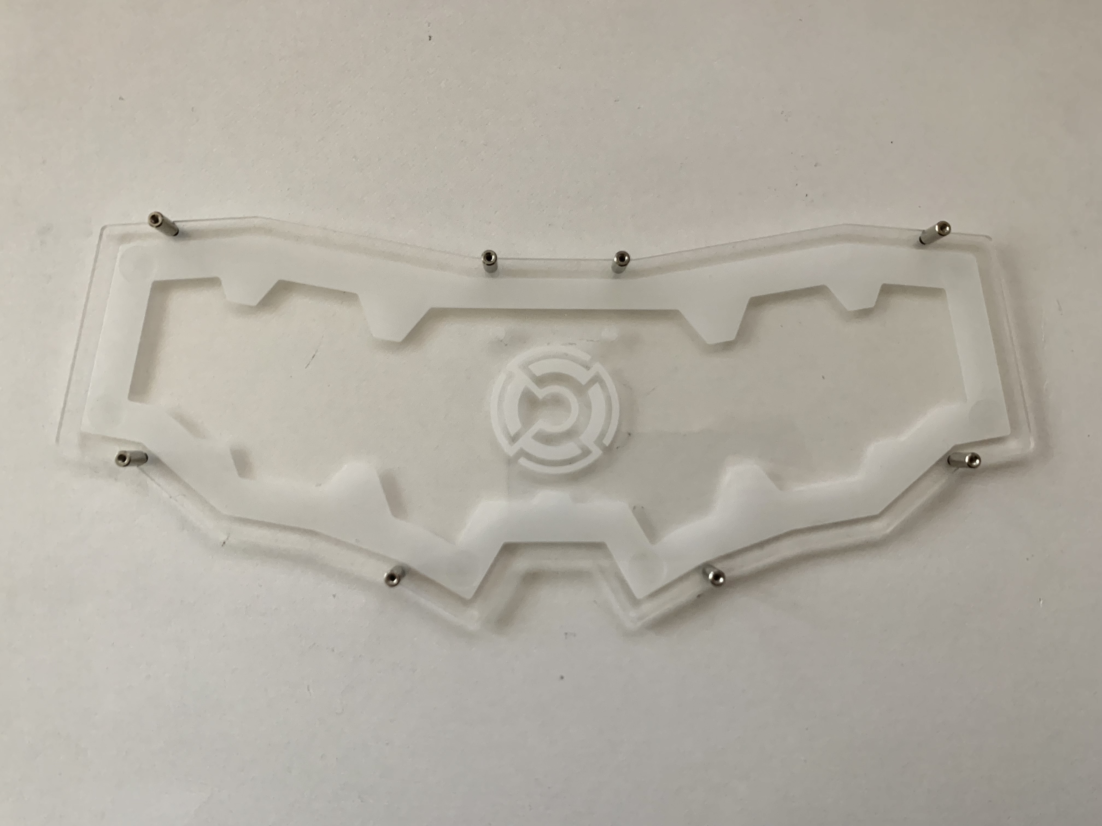
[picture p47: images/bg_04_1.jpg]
cocot36plus_bg_04_1
  

  PCBとレンズの上にボールホルダーを載せ、8mmネジを裏面からナットで固定します。  
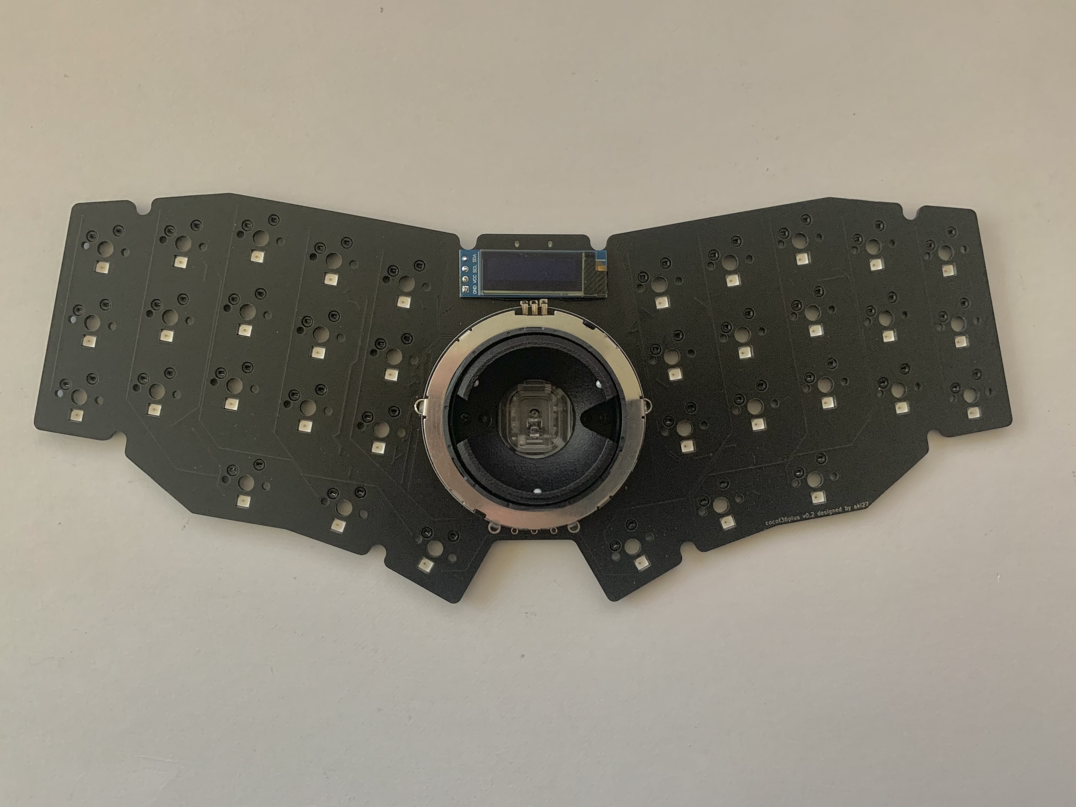
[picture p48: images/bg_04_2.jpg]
cocot36plus_bg_04_2
  

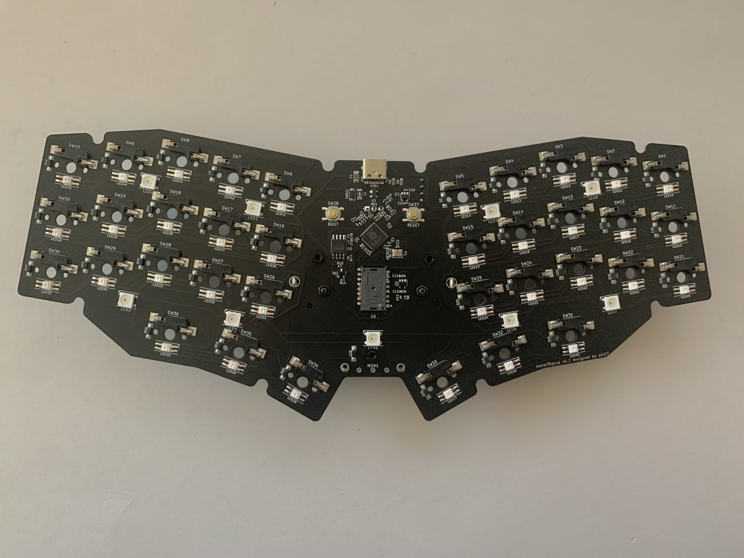
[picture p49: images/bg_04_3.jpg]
cocot36plus_bg_04_3
  

  スイッチプレートと基板を重ね、隅から順番にキースイッチをはめていきます。スイッチの向きに気を付けて、またスイッチの脚が曲がらないように真っすぐに差し込むようにしてください。  
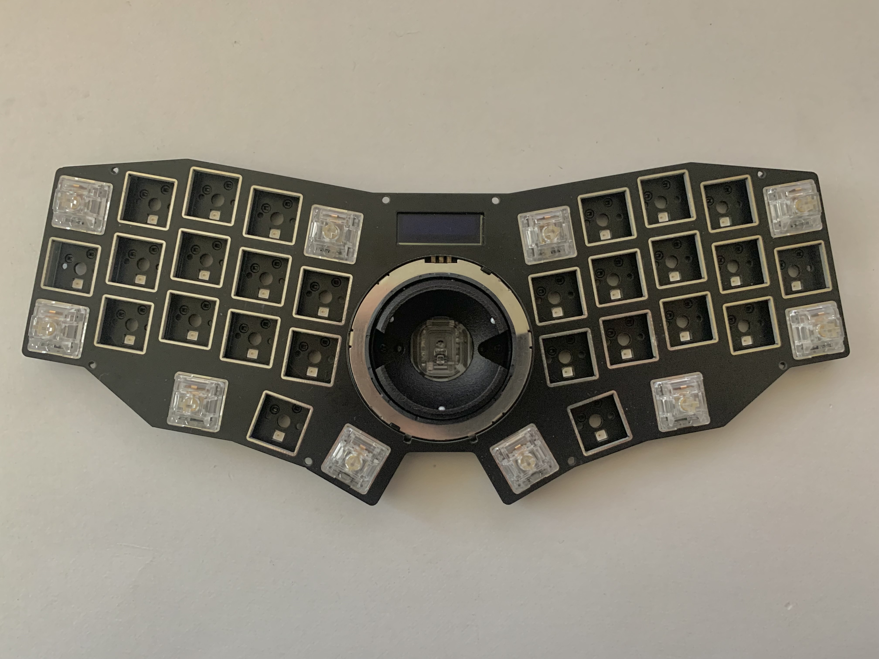
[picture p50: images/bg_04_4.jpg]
cocot36plus_bg_04_4
  

  スイッチを差し込んだスイッチプレート&基板を、ボトムプレートの上に重ねます。スイッチプレート表面から4mmネジで8か所固定します。  
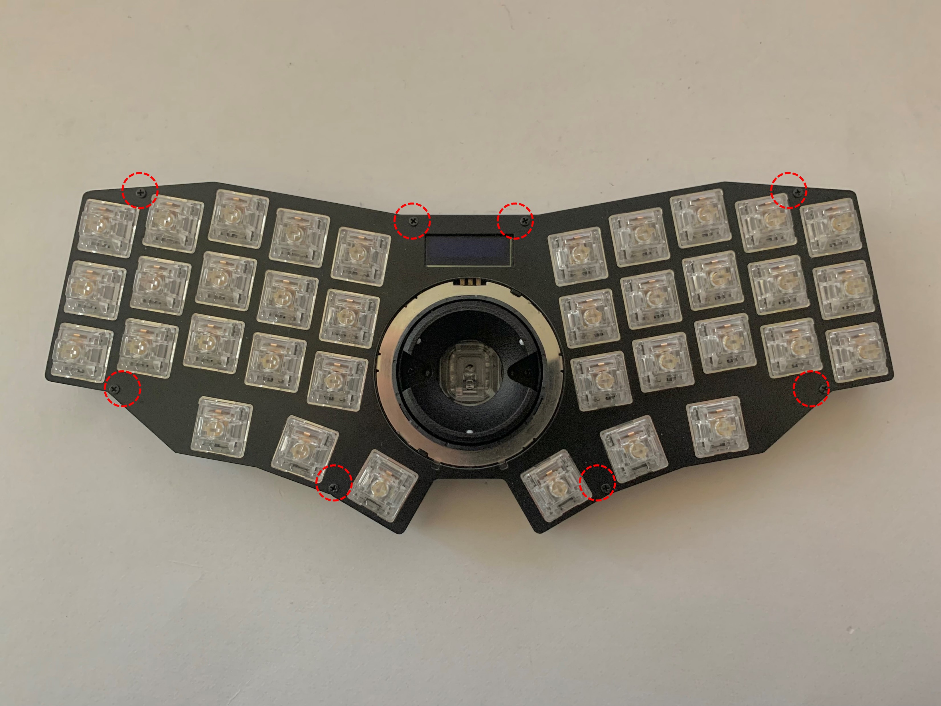
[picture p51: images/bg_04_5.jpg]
cocot36plus_bg_04_5
  

  ボールカバーをスクロールリングに装着します。緩い場合はマスキングテープや両面テープで接着面を増やすようにしてください。  
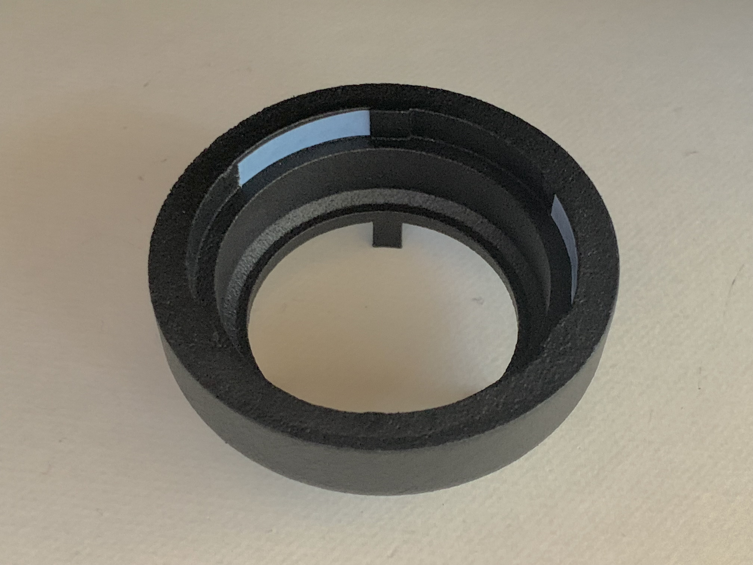
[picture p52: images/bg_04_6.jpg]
cocot36plus_bg_04_6
  

  cocot36plus_bg_04_7

  ボール、キーキャップをはめて完成です。  
  cocot36plus_bg_04_8

  cocot36plus_bg_04_9  

## ファームウェア

デフォルトのファームが書き込まれた状態でお届けしています。ご自分でファームを書き込む場合、下記手順の通り実行してください。

  - 裏面のBOOTボタンを押しながらRESETボタンを押し、ブートローダーモードに入ります。
  - その状態でRPI-RP2というドライブに[.uf2](https://github.com/aki27kbd/cocot36plus/blob/main/firmware/aki27_cocot36plus_auto_mouse.uf2)ファイルをドラッグ&ドロップすることでファームが書き込まれます。

キーマップは[こちら](https://remap-keys.app/configure)から更新可能です。  
トラックボール、LED含めて上記.uf2ファイルで確認いただけます。

REMAP

組み立て段階で動作確認をする際も、REMAPのTest Matrix Modeを使うと便利です。ただし、Test Matrix Modeではスクロールリングの回転は確認できないので、別途キー入力等で動作を試してください。

標準ファームウェアでは、トラックボールの動きを検知すると自動的にレイヤー4に移動します。レイヤー4にマウスキーなどを設定すると使いやすいです。

ソースコードは[こちら](https://github.com/aki27kbd/qmk_firmware/tree/master/keyboards/aki27/cocot36plus)を参照ください。  
また、VIA用のjsonファイルは[こちら](https://github.com/aki27kbd/cocot36plus/blob/main/firmware/cocot36plus_via.json)を参照ください。

## カスタムキーコード

  トラックボールの操作に関していくつかカスタムキーコードを設定することが可能です。スクロール関係のキーコードに関しては、デフォルトのファームでは無効になっています。（SCRL_MOはレイヤー4でのみ有効）

  Value    | Keycode   |Description
  ---------|-----------|-----------
  `0x5DA7` | `CPI_SW`  |トラックボールのCPIを変更します。デフォルトのファームウェアでは、押すたびに200→400→800→1600→3200→200…という順番でCPIが変わります。
  `0x5DA8` | `SCRL_SW` |スクロールモードにおけるセンサーの感度を変更します。数値が大きいほどスクロール量が小さくなります。
  `0x5DA9` | `ROT_R15` |マウスセンサーのＹ軸を時計回りに15度回転させます。
  `0x5DAA` | `ROT_L15` |マウスセンサーのＹ軸を反時計回りに15度回転させます。
  `0x5DAB` | `SCRL_MO` |押されている間スクロールモードになります。（デフォルトファームではレイヤー4でのみ有効）
  `0x5DAC` | `SCRL_TO` |押すたびにスクロールモードとマウスモードを切り替えます。（デフォルトファームでは無効）
  `0x5DAD` | `SCRL_IN` |スクロール方向を反転させます。（デフォルトファームでは無効）

  REMAPでカスタムキーコードを設定する場合はFunctionタブ下のカスタムキーコードを用いて設定することが可能です。  
  CustomKeycode_rev

## OLED

  OLEDにはトラックボールの情報を表示することが可能です。  
  cocot46plus_bg_oled_1

  OLED|Description
  ---------|-----------
  Current Layer|現在のレイヤーを示します。
  Scroll Status|C:カーソル/S:スクロールモードを示します。
  CPI|カーソルモードのCPIを示します。
  Scroll Divider|スクロールモードにおけるセンサーの感度を示します。数値が大きいほどスクロール量が小さくなります。
  Rotation Angle|マウスセンサーのY軸の回転角を示します。

  手の大きさやトラックボールへの手の置き方によって、操作しやすいY軸の回転角が異なります。`ROT_R15`、`ROT_L15`キーで調整しながら自分に合った設定を探してみてください。  
  cocot46plus_bg_oled_2_2

  cocot46plus_bg_oled_3_4_5

## Links

  [【大注目！】トラックボール付き自作キーボード cocot36plus/coron47plus レビュー | Trackball Mechanical Keyboard Review](https://www.youtube.com/watch?v=GIpaJPnjrzo) (by Daihukuさん)  
  トラックボールの使い心地、内部構造、スクロールリングなど紹介いただいています。

  [Gallery on Twitter](https://twitter.com/search?q=%23cocot36plus&src=typed_query&f=image)

## 終わりに
何かトラブルがあれば[Twitterアカウント](https://twitter.com/aki27kbd)までご連絡ください。

また、完成写真をSNSにアップいただけるととても励みになります。（アップするのがはばかられる方はDMで直接送りつけていただいても構いません。）

ハッシュタグは #cocot36plus です。

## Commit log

2023-12-02 add 3d print case data
    [cocot36plus_v2_TrayMountCase.stp, cocot36plus_v2_TrayMountCase_LowPro.stp]
2024-01-13 add v2 ball base 3d data
    [BallBase_34mm_Bearing.stp]
2024-11-16 add socket description
2025-06-02 add plate data
    [cocot36plus_v2_Acrylic_Bottom.dxf, cocot36plus_v2_Cover_Plate.dxf, cocot36plus_v2_Switch_Plate.dxf]
2025-06-08 add ball cover data
    [cocot36plus_v2_34mm_ballbase_rev.stp, cocot36plus_v2_BallCover_34mm_ClearResin.stp, cocot36plus_v2_BallCover_34mm_MJF.stp]
